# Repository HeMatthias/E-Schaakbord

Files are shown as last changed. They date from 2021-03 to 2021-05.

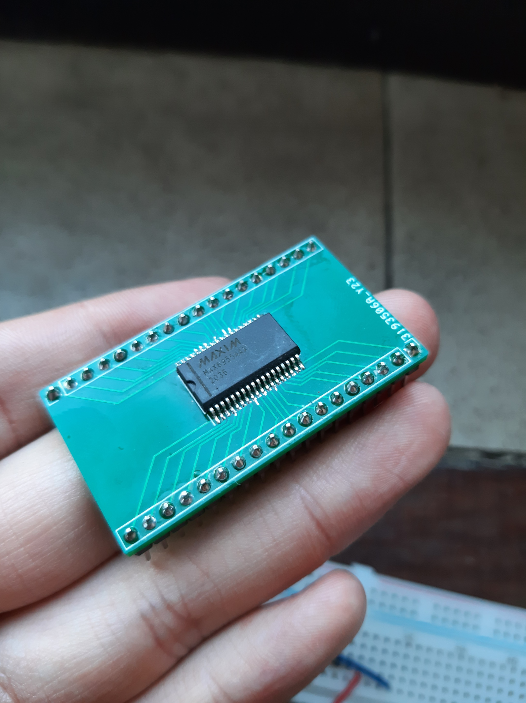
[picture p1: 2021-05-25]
Bundel/Testprint MAX6955.jpg

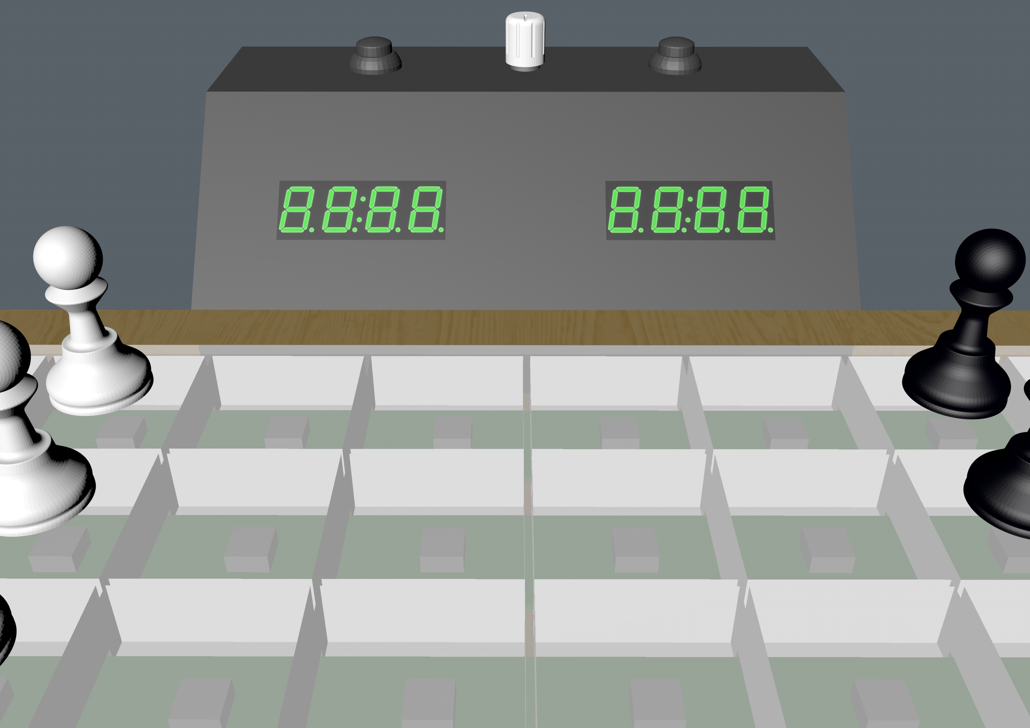
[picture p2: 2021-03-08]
VB Schaakbord2.jpg

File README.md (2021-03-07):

# **♔E-Schaakbord♔**

>#### Gemaakt door: *Hendrickx Matthias*

## Beschrijving

Het E-schaakbord is een elektronisch schaakbord dat a.d.h.v. verschillende elektronica componenten zoals RGB LED’s, sensoren, ... je interactief leert schaken.

Doordat de vakken onder de pionnen belicht worden is er de mogelijkheid om aan te tonen welke stap de pion kan zetten die men opheft of om weer te geven welke er kunnen geslagen worden.

Er bevindt zich ook rechts van het E-schaakbord 2 klokken/timers (7-segmenten) die men eventueel kan instellen hoeveel tijd iedere persoon kan spelen.

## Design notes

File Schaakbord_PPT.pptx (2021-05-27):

## Project: E-Schaakbord

Matthias Hendrickx

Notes: Mijn naam is Matthias Hendrickx, ik ben 20 jaar en heb de richting elektriciteit-elektronica gestudeerd.

Vandaag ga ik u wat meer vertellen over mijn project genaamd E-schaakbord.

## Schaakbord

- Inleiding
- Hardware
- Besluit
- Demonstratie

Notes: Eerst ga ik een inleiding geven, vervolgens de hardware uitleggen,
mijn besluiten trekken en ten slotte een demonstratie geven.

## inleiding

Wat?
Hoe?
Problemen?
Oplossingen:

Elektronisch Schaakbord
STM32 (in C)
Complexe driver, afstand bepalen
Testprint, opzoekingswerk + berekening

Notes: Wat is mijn project en hoe heb ik verschillende dingen moeten oplossen?
Mijn project gaat over een elektronisch schaakbord dat verschillende functies heeft, zoals het magnetisch bepalen waar de pionnen staan.
Het volledige schaakbord wordt bestuurd door middel van een STM32 die ik in C taal geprogrammeerd heb.
Hierbij heb ik mijn eigen library’s gemaakt voor de verschillende componenten die ik later uitleg.
Tijdens het kiezen van de juiste componenten begreep ik niet hoe een IC werkte,
daarmee heb ik een testprint gemaakt om deze volledig uit te testen.
Om de afstand van de pionnen te bepalen heb ik moeten opzoeken hoe ver magneet sensoren kunnen schakelen,
en heb ik moeten berekenen de afstand van het belichte oppervlak.

## Hardware – Blokschema

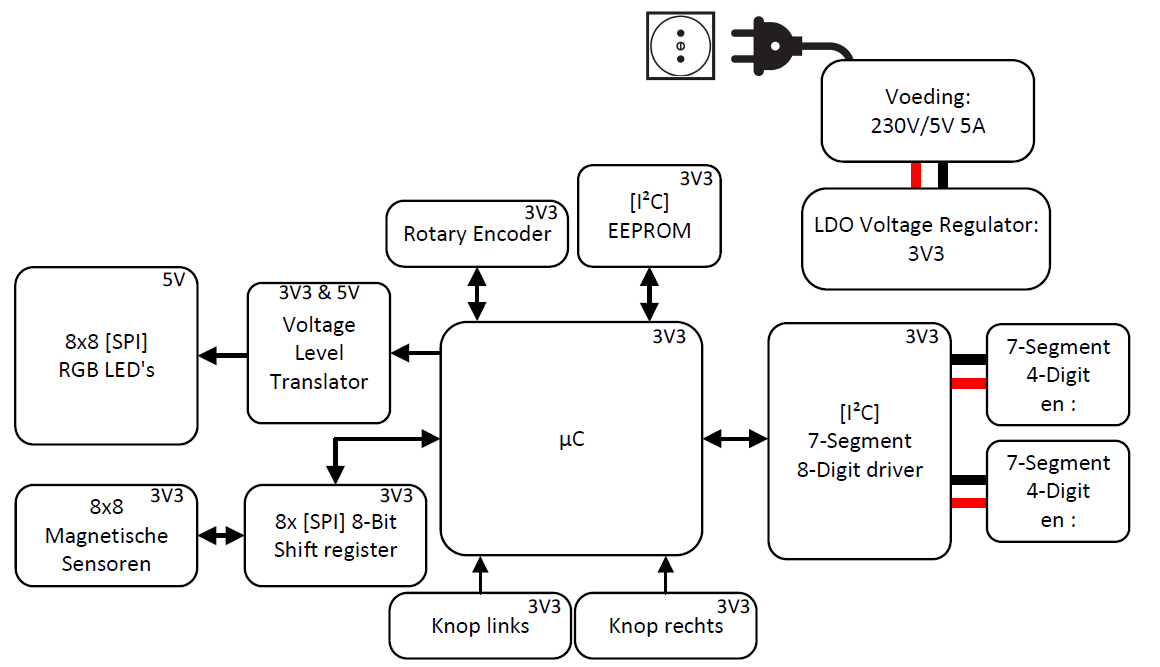
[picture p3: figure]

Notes: Dit is het blokschema van het E-Schaakbord, iedere blok ga ik in de volgende slides bespreken.

## Hardware – Voeding

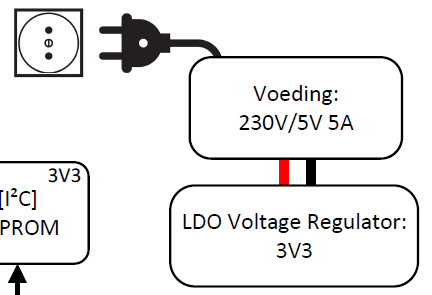
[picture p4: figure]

5V Voeding:
5V x 6A = 30W
LDO Regelaar 3V3: (NCP1117)
5V → 3V3
1500mA Max > ±306mA
IQMAX = 10mA

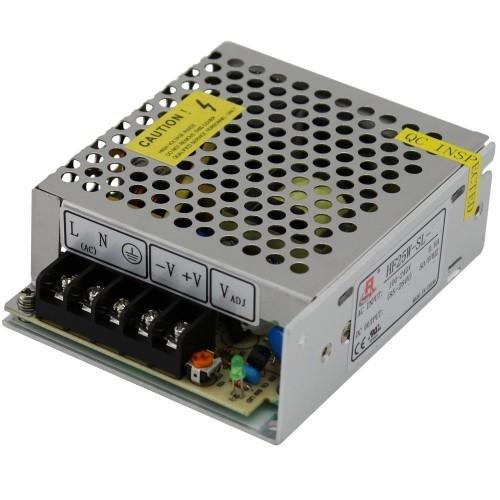
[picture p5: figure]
5V 5A Power Supply at Rs 250/piece | CCTV Power Supply | ID: 17931879912
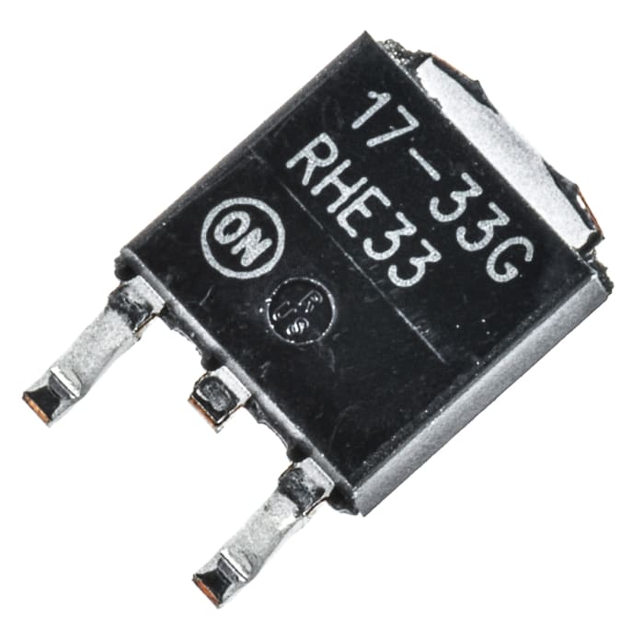
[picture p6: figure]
NCP1117DT33G ON Semiconductor | ON Semiconductor NCP1117DT33G, LDO Regulator, 1A, 3.3 V, ±1% 3-Pin, DPAK | 516-5865 | RS Components

## Hardware – STM32F1xx

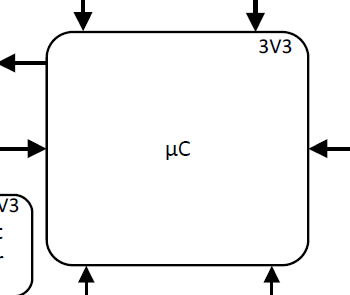
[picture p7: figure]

- µC: (STM32F101RDT6)
  - 32-bit
  - ARM Cortex-M3
  - 36MHz
- Programmeren via ST-Link V2:
  - USB naar SWD(Seriële Wire Debugger)
  - Boot mode in ROM

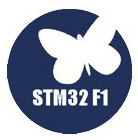
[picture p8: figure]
STM32F1 - Sklep Kamami
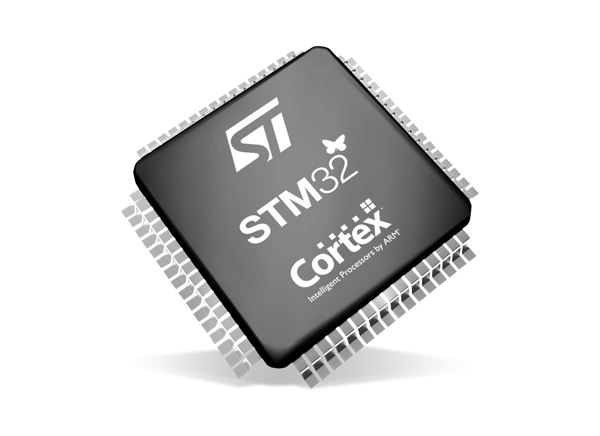
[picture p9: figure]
STM32 Microcontrollers - STMicro | Mouser
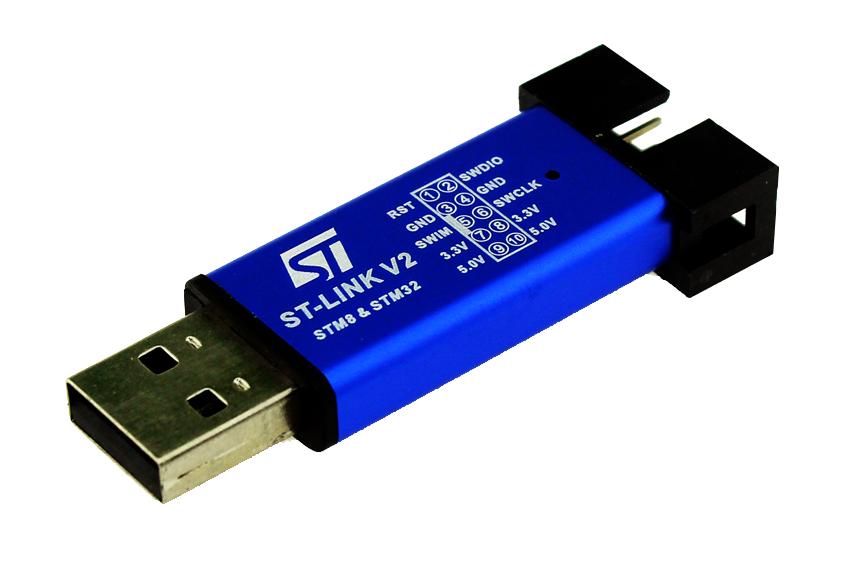
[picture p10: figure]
ST-Link V2 STM8 / STM32 programmer - Opencircuit

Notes: Zoals ik al eerder zei zal ik gebruik maken van de STM32 hieruit heb ik de STM32F101 gekozen, deze had de gewenste protocol poorten,
Deze is een 32-bit µC, en heeft een ARM Cortex-M3 hiermee kan ik zeer eenvoudig in C programmeren.
Verder laat ik de µC ook draaien op 36MHz.
Om de STM32 te programmeren maak ik gebruik van de ST-Link V2, die ik gebruik als Seriele Wire Debugger.
Het programma zal ik ook in het systeem geheugen steken, de ROM.

## Hardware – Geheugen

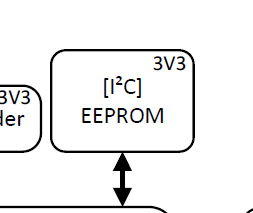
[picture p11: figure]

- EEPROM: (M24C04)
  - Opslaan score vorig spel
  - I²C (SCL, SDA)
  - 4kbit

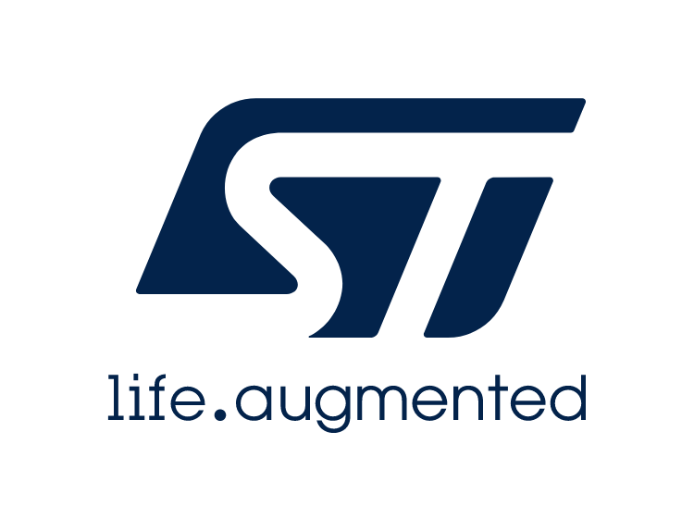
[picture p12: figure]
Home - STMicroelectronics
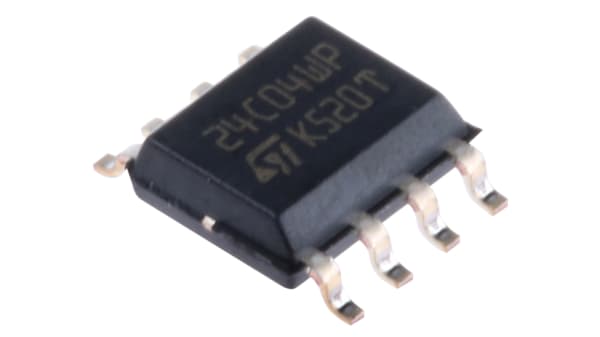
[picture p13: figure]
Mémoire EEPROM en série, M24C04-WMN6P, 4Kbit, 900ns SOIC, 8 broches | RS Components

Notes: Omdat ik niet zeker was of ik veel software moest permanent opslaan maak ik toch gebruik van een EEPROM.
Hiermee zal ik de vorige score van het spel opslaan zodanig dat er met dezelfde score verder gespeeld kan worden.
Deze EEPROM stuur ik aan via I²C en maak ik dus gebruik van een Seriele klok en de Seriele data.
Ik heb gekozen voor een maximale opslag capaciteit van 4kilo bits.

## Hardware – Interface

- Drukknop:
  - Ontdenderen
τ = R x C = 20kΩ x 100nF
τ = 2mS ≈ 3V3 x 66,6% = 2,2V = “1”
- Rotary Encoder:
  - Links & rechts draaien
  - Knop wanneer ingedrukt

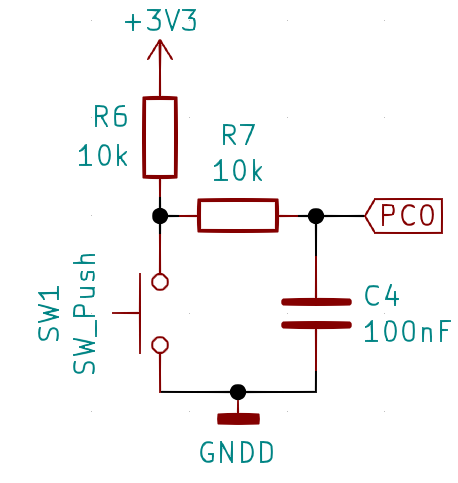
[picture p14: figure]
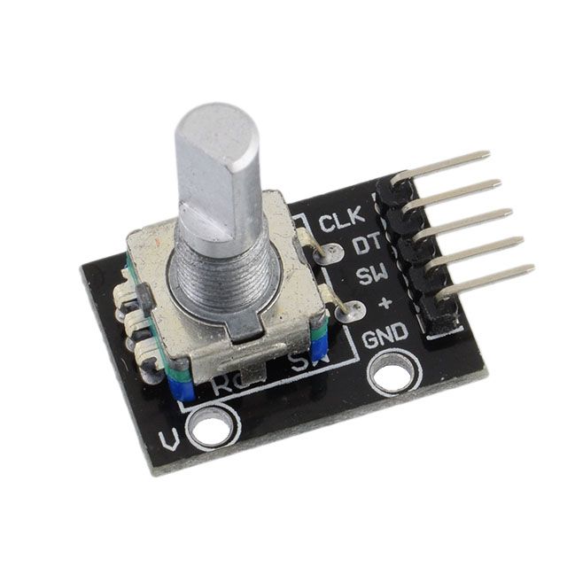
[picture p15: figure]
Rotary encoder moduly | GM electronic COM

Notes: Daarnaast maak ik ook gebruik van 2 drukknoppen, deze worden gebruikt voor de schaakklok te activeren.
Deze zal ik ook hardware matig ontdenderen, deze heb als volgende berekend:
Tau = de weerstand maal de condensator, hiermee kom ik uit op 2mS.
Dan bedraagt de spanning 2,2V en is dus een logische één
Een rotary encoder gebruik ik om op voorhand de schaakklok in te stellen en de kleur van de vakken te kiezen.
Deze kan men naar links en rechts draaien en ook induwen om de selectie te bevestiggen.

## Hardware – SENSOR

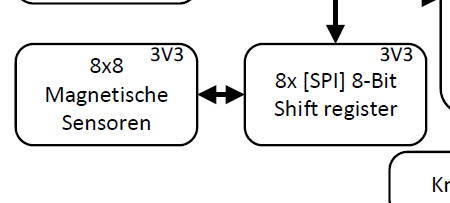
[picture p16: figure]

Magneet sensor: (AH3572)
Omnipolair (N & Z)
20 gauss
Open Drain (Pull-up)
Shift register: (SN74HC165)
PISO (Parallel In Serieel Out)
SPI (SCK → CLK | CS → SH/LD | MISO → Qh)

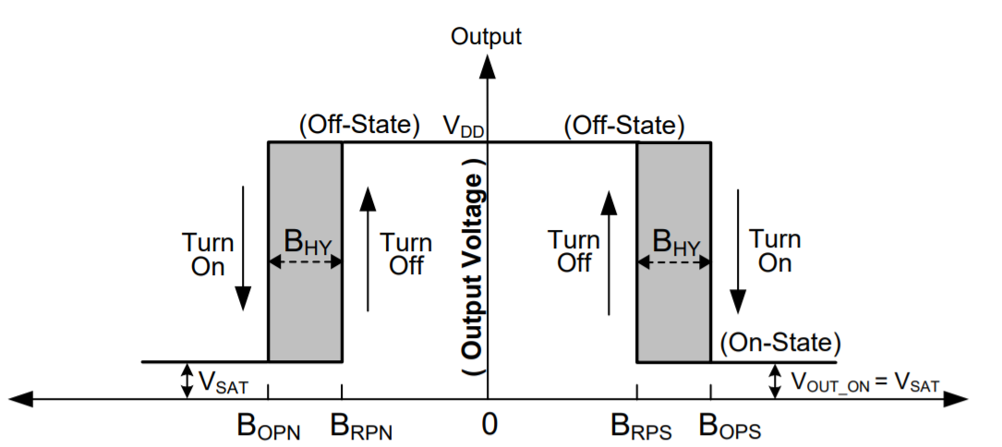
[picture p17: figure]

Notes: Voor het kiezen van een sensor moest ik opzoek gaan naar een magneet sensor.
Hiervoor koos ik een omnipolaire magneet sensor te gebruiken,
deze zullen schakelen als de Noord of de Zuid in sterker is dan 20 gauss of te wel 2milli Tesla.
De uitgang van de AH3572 is een open drain en zal ik via een externe pull-up weerstand schakelen.
Omdat ik 64 magneet sensoren heb zal ik gebruik maken van een shift register.
Hierbij koos ik voor een PISO (parallel in Serieel Uit)
Deze kan ik ook aansturen via het SPI protocol.

## Hardware – RGB LED’s

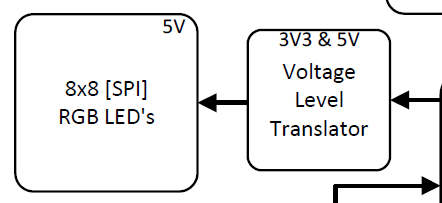
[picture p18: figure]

Adresseerbare RGB LED’s: (APA102C)
5V!
SPI (CLK, DI, ~~CS~~)
Globale intensiteit
RGB kleur intensiteit
Voltage Translator: (SN74LVC2T45)
5V → 3V3

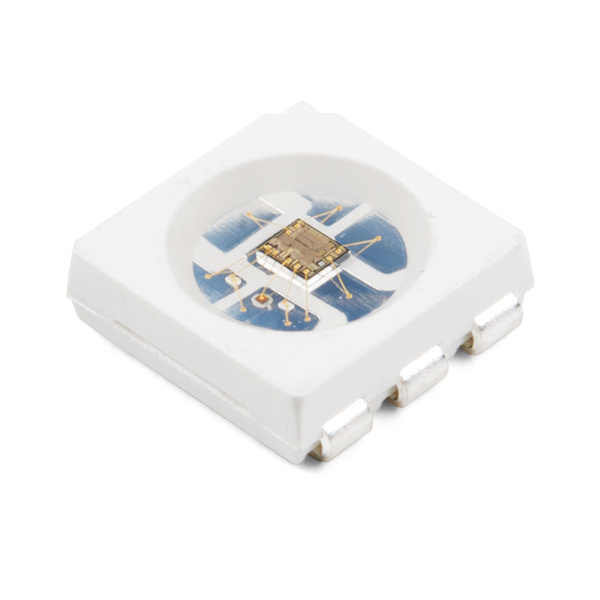
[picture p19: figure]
APA102 Addressable LED Hookup Guide - learn.sparkfun.com

## Hardware – Klok

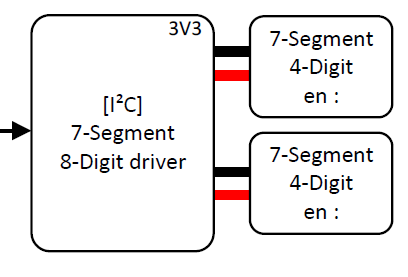
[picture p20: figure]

7 Segment 4 Digit :
Groen
20mA/segment
3200µcd
7 Segment Driver: (MAX6955)
I²C (SCL, SDA)
Tot 16 digit 7 segment aansturen
Individuele intensiteit controle

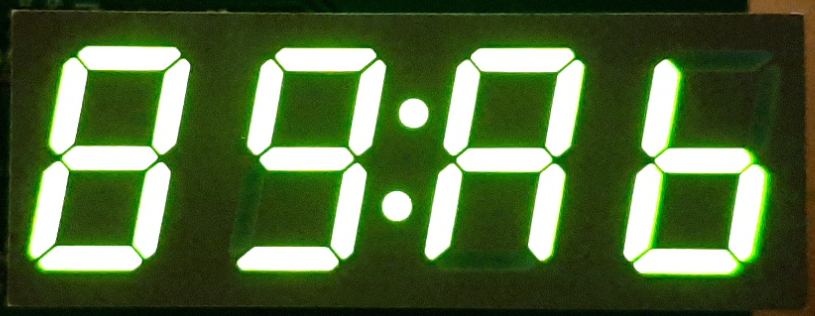
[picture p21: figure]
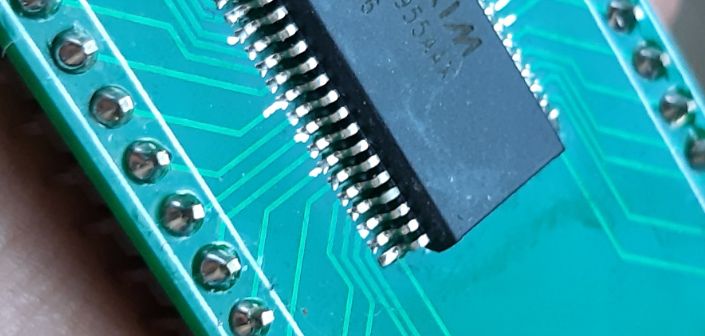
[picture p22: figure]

## besluit

De behuizing | Hardware geen fout
PCB paar fouten Pin ontbreekt | Software verliep vlot
Vertraging PCB | Solderen van SMD
| Afstand klopt

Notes: Ten slotte de besluiten die ik doorheen het project ontdekt heb.

## Demonstratie

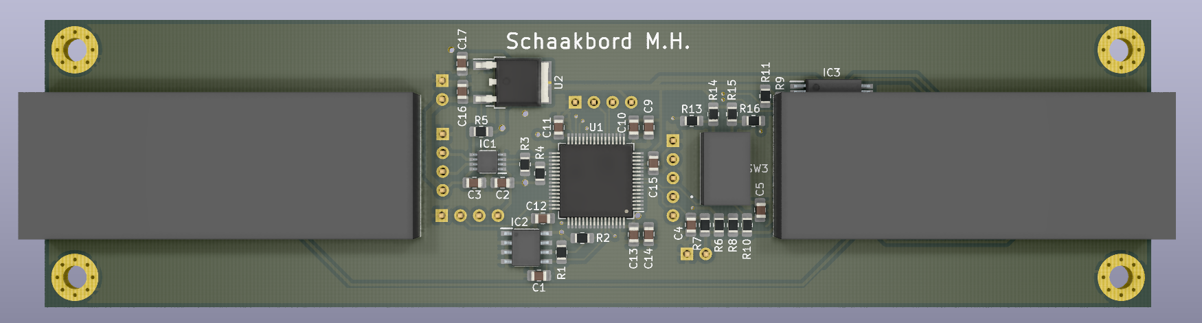
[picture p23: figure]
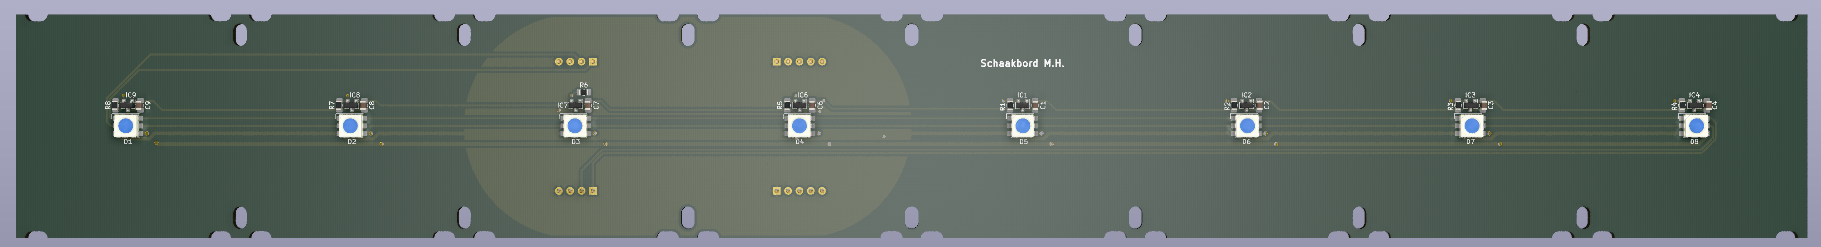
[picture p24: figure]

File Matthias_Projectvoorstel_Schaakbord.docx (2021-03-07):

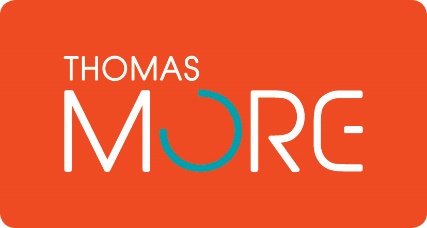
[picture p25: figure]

| Naam Matthias Hendrickx r-nummer r0782520 1 Vak Practice Enterprise 2 1 Datum 29/11/2020 1 Klas Embedded-Hardware 2EH1 1

Projectvoorstel: E-Schaakbord

Korte beschrijving

Voor het vak Practice Enterprise 2 zal ik een educatief E-schaakbord maken waar de E staat voor Elektronisch. Dit doe ik a.d.h.v. verschillende RGB LED’s, 7-Segmenten, sensoren en meer. De bedoeling is dat je met dit bord leert schaken. Aan het begin van het spel kan men de speeltijd instellen a.d.h.v. een rotary encoder en doordat de vakken onder de pionnen belicht worden is er de mogelijkheid om aan te tonen welke stappen iedere pion kan zetten.

Blokdiagram

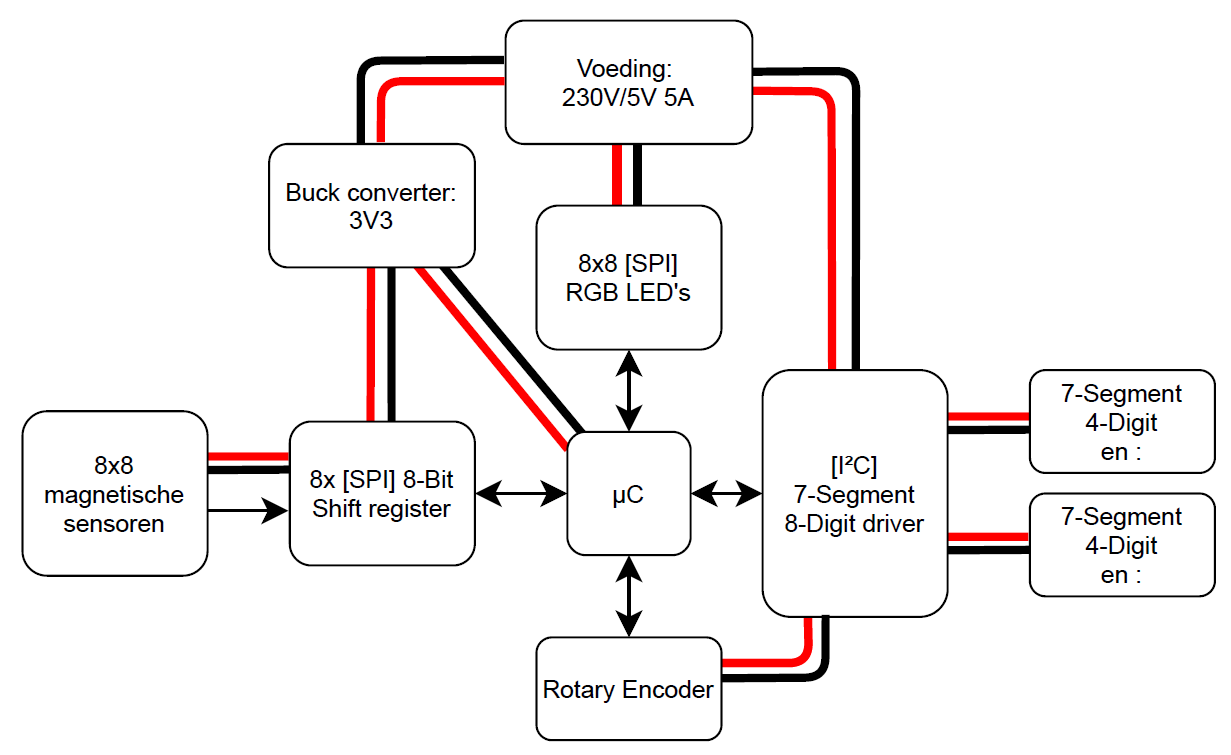
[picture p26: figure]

- Voeding: Mean Well, RS-25-5
- Buck converter: Texas Instruments, TPS62203
- µC: STMicroelectronics, STM32F101RB
- RGB LED’s: Sparkfun, RGB APA102C 5050
- Rotary encoder: Bourns, PEC11R-4225F-S0012
- Shift register: Texas Instruments, SN74HC165
- Magnetische sensor: Toshiba, TCS40DPR
- 7-Segment 8-Digit driver: Maxim Integrated, MAX6955
- 7-Segment 4-Digit display: Vishay, TDCG1050M

Componenten/tool keuze

STM32F101 - Arm Cortex-M3 Microcontrollers (MCU) 36 MHz - STMicroelectronics

Als microcontroller (µC) heb ik gekozen voor de STM32F1 series omdat deze een goed prijs/kwaliteit bood, in deze series heeft men de keuze tussen 16kB tot 1MB Flash geheugen waarvan ik 128kB koos. Daarnaast gebruik ik de 64-pin LQFP-package voor als ik eventueel niet toekom aan geheugen kan ik verhogen zonder de PCB aan te passen.

STMicroelectronics Updates STM32CubeMX MCU Configurator with Multi-Panel GUI for Improved Developer Experience

De STM32F1 series maakt ook gebruik van de wel bekende STM32CubeIDE waarin ik men µC kan instellen en programmeren.

Om mijn programma te uploaden en te debuggen zal ik gebruik maken van

een ST-Link V2.

Ximimark ST-Link V2 Shell Programming Un- Buy Online in Trinidad and Tobago at Desertcart

Hierdoor kan ik vlot communiceren van de computer naar de µC en visa versa.

Marktonderzoek(wat bestaat er al?)

Over het algemeen bestaan er 2 soorten elektronische schaakborden.

- Waarmee men tegen een computer speelt. Deze werken meestal op batterij omdat de meeste via een scherm de posities weergeven.


- Of voor schaakwedstrijden met een aparte digitale klok. Hier wordt het schaakbord via een aparte kabel of bluetooth verbonden met de klok. Deze worden meestal gevoed door hem in het stopcontact te steken.

Schachcomputer DGT 3000 Pi Schachcomputer

Technologie verkenning(principes, evaluatieborden, papers, ...)

Voor technologie verkenning ben ik opzoek gegaan naar een geschikte microcontroller(µC). Hiervoor heb ik van alle parameters opgezocht van welke soorten allemaal bestaan bv: 8-bit, 32-bit, PIC, ARM, AVR en nog veel meer. Ten slotte heb ik gekozen voor ARM-cortex met 32-bit zodanig dat mijn code niet te complex wordt en geen pagina’s lang is.

Daarna ben ik opzoek gegaan naar µC fabrikanten hiervoor heb ik verschillende websites bestudeert zoals: Microchip, Infineon, Texas Instruments, ...

Ten slotte vond ik STMicroelectronics de meest interessantste omdat ik meer bekend ben met deze fabrikant en een goed platform heeft om te programmeren en dergerlijk. Bij Componenten/tool keuze ga ik wat meer in detail welke STMicroelectronics ik gekozen heb.

Budget raming


Als budget raming heb ik iedere blok van het blokdiagram op de webshop van Mouser opgezocht en kwam ik ±60€ uit +30€ voor de behuizing en dergerlijk.

Pagina 2 van 2

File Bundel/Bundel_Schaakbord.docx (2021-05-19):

# Inhoudstafel

# Voorwoord

TEKST TEKST TEKST ...

# Inleiding

Deze bundel gaat over het project dat ik gemaakt heb voor het vak Practice Enterprise 2, hierbij waren de minimale vereisten dat ik een PCB ontwerp, Software schrijf (liefst in C op een µController) en ten slotte het project een nuttige toepassing heeft. Het is ook belangrijk dat er een veilig project gekozen werd en de kostprijs niet te hoog lag.

Na enkele projectjes dat ik heb voorgesteld koos ik om een elektronisch educatief schaakbord te maken. Hiermee zouw u dan de mogelijkheid krijgen om te leren hoe men iedere pion zet en de werking van een schaakklok. Daarnaast bevat het schaakbord over een puntensysteem dat bijgehouden wordt.

# 1 Hardware

## 1.1 Blokschema


In het blokschema zien we hoe de verschillende blokken verbonden zijn met elkaar maar dit in een vereenvoudigde weergave. Hierbij kan je zien hoe alles logisch met elkaar verbonden is d.m.v. voedingsaansluitingen en communicatielijnen.

Figuur 1, Blokschema

## 1.2 Schema’s


Dit is het aansluiting schema van het hoofdbord, hierin zit: de µC, 7 Segmenten, Rotary Encoder ... Later wordt ieder deel nog besproken.

Figuur 2, Schema hoofdbord


Dit is het aansluiting schema van de borden die zich onderaan de pionnen liggen, Later wordt ieder deel besproken.

Figuur 3, Schema pionnen

## 1.3 Beschrijving

Hierin ga ik ieder deel bespreken en uitleggen hoe ik eventueel iets berekend heb.

### 1.3.1 Schakelende voeding


Het E-Schaakbord wordt gevoed door de 230V AC netspanning die wordt omgezet naar 5V DC d.m.v. een schakelende voeding. De voeding die ik gekozen/berekend heb kan maximaal 5A leveren of in andere woorden 5V*5A=25W .

Dit heb ik berekend a.d.h.v. het maximaal vermogen dat gebruikt kan worden op te tellen van ieder component. Daarmee heb ik gebruik gemaakt van de maximale spanning en stromen die uit de datasheet komen van ieder component.


Tabel 1, Vermogen berekening

Figuur 4, Voorbeeld voeding

Zoals u merkt heb is mijn voeding’s keuze redelijk krap genomen, dit is doordat ik het maximale berekend heb en daarmee juist gekozen heb voor 5A. Het verbruik wordt beperkt d.m.v. de software die ik er insteek, omdat ik nooit al mijn RGB LED’s tegelijk de kleur wit ga maken zal de stroom dus beperkt blijven.

APA102C (RGB Addressable LED’s): kleur Wit Itot=Uin*Iin*Aantal=5V*24,5mA*3*64=4,704A Ptot=Uin*Itot=5V*4,704A=23,52W

APA102C (RGB Addressable LED’s): kleur Blauw Itot=Uin*Iin*Aantal=5V*24,5mA*64=1,568A Ptot=Uin*Itot=5V*1,568A=7,84W

MAX6955 (7 Segment Driver): Ptot=(Uin*35mA)+(Uin -Uled)(DUTY*Iseg*Ndigit) Ptot=(3,3V*35mA)+(3,3V -2V)(15/16*25mA*8)=243,866mW Itot=(Ptot)/(Uin)=(243,866mW)/(3,3V)=73,899mA

STM32F101RDTx (µC):


Itot is gesimuleerd a.d.h.v. CubeMX zijn PCC Tool.

Hierbij heb ik alles ingesteld op het maximum dat ik kan gebruiken i.v.m. het schaakbord: HSI PLL, de CPU Frequency, I/O en meer.

Itot≈20mA

Ptot=Uin*Itot=3,3V*20mA=66mW

Figuur 5, Simulatie stroomverbruik

AH3572 (Magnetic Sensor): Itot=Uin*Iin*Aantal=3,3V*3mA*64=192mA Ptot=Uin*Itot=3,3V*192mA=633,6mW

NCP1117 (LDO Voltage Regulator): Itot=(Uin-Uuit)*Iq=(5,2V-3,2V)*10mA=20mA Ptot=(Uin-Uuit)*Itot=(5,2V-3,2V)*20mA=40mW

### 1.3.3 LDO Voltage Regulator

Nadat de 230V AC omgezet is naar 5V DC zal ik deze 5V omzetten naar 3V3, hiermee zal ik de andere componenten voeden buiten de RGB LED’s.

Ik heb gekozen voor een LDO omdat:

- Het maximaal vermogen onder de 1W was en dus dit vermogen nog gedissipeerd kan worden d.m.v. een LDO.
- Het voordeel is ook dat LDO’s qua structuur simplistisch zijn en dus onafhankelijk zijn van een externe spoel i.t.t. een Buck-Converter.

A.d.h.v. de vorige berekeningen (Tabel 1) kwam ik uit dat de LDO een minimaal vermogen van ±983mW gedissipeerd wordt. Hiermee ben ik dan aan de slag gegaan en opzoek gegaan naar een LDO en kwam ik uit op de NCP1117.

Deze heb ik gekozen door de volgende berekeningen te maken: P_(DMAX) =(T_J – T_A)/(Θ_(JA))=(150°C-40°C)/(67°C/W)=1642mW

P_(MAX) <P_(DMAX) →983mW<1642mW

Deze berekeningen heb ik geraadpleegd via een handig document van Microchip<link>

### 1.3.4 µC

Dit is een zeer belangrijk keuze die gemaakt moet worden, daarmee heb ik genoeg research gedaan op het internet d.m.v. online guides op te zoeken en meer.

De eerste vraag die ik mezelf stelde is of ik een 8-bit of 32-bit microcontroller kies. Ik koos voor een 32-bit microcontroller wegens volgende redenen:

- Communicatieprotocollen zoals SPI & I²C zijn eenvoudiger te implementeren.
- Om lengte/grootte van software te beperken.
- Eenvoudiger te debuggen.

Nu was de keuze voor welke fabrikant ik zal gaan, hier waren vooral 2 uitblinkers bij de STM32 of PIC32. Ik koos voor de STM32 wegens volgende redenen:

- Meer gekend in hoe deze ge programmeert wordt en debugt.
- Zeer stabiel en handige Toolchain/IDE ondersteuning.

Ten slotte ben ik opzoek gegaan naar een STM32 die een genoeg aantal I²C en SPI-protocollen had en die genoeg geheugen heeft.


Toen kwam ik uit op de STM32F101RDT6, deze bevindt zich in een LQFP-64 package dat nog handsoldeerbaar is en ook de mogelijkheid heeft in dezelfde package een groter geheugen te kiezen of een andere reeks.

Figuur 6, Circuit Diagram

### 1.3.5 RGB LED’s

Om de schaakvakken een kleur te geven maak ik gebruik van adresseerbare RGB LED’s, hierdoor kan ik elk vak individueel een andere kleur geven wat dat belangrijk is voor aan te duiden wat de pion hun mogelijke zetten zijn en meer.

Ik heb gekozen om gebruik te maken van de APA102C LED’s omdat:

- Worden aangestuurd via het standaard SPI-Protocol.
- Heeft een snellere CLK-frequentie maximaal 1,2MHz.


- Beschikt over een aparte PWM-instelling om de lichtsterkte te regelen.

Figuur 7, Illustratie APA102C

Understanding the APA102 “Superled” – Tim's Blog

Zoals u hierboven ziet wordt de APA102C’s aangestuurd:

Figuur 8, APA102C SPI-Protocol

Eerst wordt er een Start Frame gestuurd met 4 bytes die ‘0’ zijn.

Daarna wordt er de data van de eerste LED gestuurd met als inhoud:

1. “111” om te beginnen, 3 bits.
2. Daarna de data wat de licht intensiteit is van al de LED’s, 5bits.
3. De lichtintensiteit van de kleur blauw, 1 byte.
4. De lichtintensiteit van de kleur groen, 1 byte.
5. De lichtintensiteit van de kleur rood, 1 byte.

Vervolgens stuurt men de data door van de tweede LED.

Ten slotte kan men een eind frame sturen die bestaat uit allemaal enen, de grote van deze frame is gelijk aan het totaal aantal LED’s delen door 2.

Dus het schaakbord bestaat uit 64 RGB LED’s, dat wil zeggen dat er 32 keer 4 bytes die ‘1’ zijn (eind frame) verstuurt moet worden. Het is gemakkelijker om op het einde een Start frame sturen om terug opnieuw te beginnen waardoor ik zo min mogelijk tijdverlies.

### 1.3.6 Voltage Level Translator


Om de APA102C’s te laten communiceren met de µC zal ik de 3V3 logica moeten omzetten naar 5V logica. Om deze om te zetten maak ik gebruik van een Voltage Level Translator. Ik heb gekozen voor de SN74LVC2T45, hiermee zal ik de SCK (seriële clock) en de SDI (seriële data in) omzetten naar 5V logica.

Figuur 9, Schema Voltage Translator

### 1.3.7 Rotary Encoder

Voor het schaakbord gebruiksvriendelijker te maken bevindt er zich een rotary encoder tussen de 2 drukknoppen op de schaakklok. Hiermee kan voor het spel begint de tijden ingesteld worden en de kleur van de schaakvakken.

In-Depth: How Rotary Encoder Works and Interface It with Arduino

Een rotary encoder werkt als volgend:

Figuur 10, Werking Rotary Encoder

Wanneer er één stand in wijzerzin (↻) gedraaid wordt zal Terminal A 90° voor-ijlen omdat deze voor Terminal B contact zal maken met de GND of de 3V3. Als daar na gelijk er één stand in wijzerzin (↻) opnieuw gedraaid wordt zal nu Terminal B op hetzelfde contact van Terminal A staan.

Dit is omgekeerd als men één stand in tegenwijzerzin (↺) draait zal Terminal B 90° voor-ijlen omdat deze voor Terminal A contact zal maken met de GND of de 3V3. hetzelfde als er daar na gelijk één stand in tegenwijzerzin (↺) opnieuw gedraaid wordt zal nu Terminal A op hetzelfde contact staan als dat van Terminal B.


Deze terminals worden vervolgens zo aangesloten op de STM32:

Figuur 11, Schema Rotary Encoder

In de software zal nu gewoon iedere pin continu uitgelezen worden en als er een verandering plaats vindt zal men te weten komen welke richting er gedraaid werd.

De rotary encoder bevat ook een schakelaar die schakelt wanneer op de knop geduwd wordt, hiermee is alles wat meer gebruiksvriendelijk zoals om een actie te voltooien.

### 1.3.8 EEPROM

EEPROM of Electrically Erasable Programmable Read-Only Memory is een geheugen IC die data opgeslagen houdt terwijl de IC niet gevoed wordt, dit heet men ook permanent geheugen. EEPROM’s kunnen ook hun blokken data (1 byte) individueel her programmeren waardoor er niet alles verwijderd moet worden. Het nadeel is wel dat deze niet oneindig keer herschreven kan worden, maar tegenwoordig kunnen de meeste meer dan 1 miljoen keer herschreven worden.

Ik heb gekozen voor de M24C04 omdat deze via I²C te werk gaat en een geheugen heeft van 4kbits of 512bytes. Hierin zal ik de score zetten van het vorig spel.

# besluit….

Typ hier je besluit

Pagina 2 van 2

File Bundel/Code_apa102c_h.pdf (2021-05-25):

APA102C.h

2 * APA102C.h
7
8 #ifndef INC_APA102C_H_
9 #define INC_APA102C_H_
10
11 void LED_Rood(uint8_t brightness);
12 void LED_Groen(uint8_t brightness);
13 void LED_Blauw(uint8_t brightness);
14 void LED_RGB(uint8_t brightnessR, uint8_t brightnessG, uint8_t brightnessB); 15 void LED_Start(void);
16
17 #endif /* INC_APA102C_H_ */
18

Page 1

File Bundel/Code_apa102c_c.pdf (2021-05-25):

APA102C.c; 2 * APA102C.c 7 #include "main.h" 8 9 uint32_t t = 1; 10 int8_t i = 0; 11 12 void LED_Rood(uint8_t brightness){ 13 for (i = 0; i < 8; i++) { 14 HAL_GPIO_WritePin(SPI2_MOSI_GPIO_Port,SPI2_MOSI_Pin,GPIO_PIN_SET); 15 SysTickDelayCount2(t); 16 HAL_GPIO_WritePin(SPI2_SCK_GPIO_Port,SPI2_SCK_Pin,GPIO_PIN_SET); 17 SysTickDelayCount2(t); 18 HAL_GPIO_WritePin(SPI2_SCK_GPIO_Port,SPI2_SCK_Pin,GPIO_PIN_RESET); 19 } 20 for (i = 0; i < 16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

APA102C.c

63 SysTickDelayCount2(t);
64 HAL_GPIO_WritePin(SPI2_SCK_GPIO_Port,SPI2_SCK_Pin,GPIO_PIN_SET); 65 SysTickDelayCount2(t);
66 HAL_GPIO_WritePin(SPI2_SCK_GPIO_Port,SPI2_SCK_Pin,GPIO_PIN_RESET); 67 }

### 68 for (i = 0; i < 8; i++) {

69 HAL_GPIO_WritePin(SPI2_MOSI_GPIO_Port,SPI2_MOSI_Pin,GPIO_PIN_RESET); 70 SysTickDelayCount2(t);
71 HAL_GPIO_WritePin(SPI2_SCK_GPIO_Port,SPI2_SCK_Pin,GPIO_PIN_SET); 72 SysTickDelayCount2(t);
73 HAL_GPIO_WritePin(SPI2_SCK_GPIO_Port,SPI2_SCK_Pin,GPIO_PIN_RESET); 74 }
75 }
76

### 77 void LED_Blauw(uint8_t brightness){ 78 for (i = 0; i < 8; i++) {

79 HAL_GPIO_WritePin(SPI2_MOSI_GPIO_Port,SPI2_MOSI_Pin,GPIO_PIN_SET); 80 SysTickDelayCount2(t);
81 HAL_GPIO_WritePin(SPI2_SCK_GPIO_Port,SPI2_SCK_Pin,GPIO_PIN_SET); 82 SysTickDelayCount2(t);
83 HAL_GPIO_WritePin(SPI2_SCK_GPIO_Port,SPI2_SCK_Pin,GPIO_PIN_RESET); 84 }

### 85 for (i = 7; i >= 0; i--) {

86 uint8_t k = brightness >> i;

### 87 if (k & 1){

88 HAL_GPIO_WritePin(SPI2_MOSI_GPIO_Port,SPI2_MOSI_Pin,GPIO_PIN_SET); 89 }else{
90 HAL_GPIO_WritePin(SPI2_MOSI_GPIO_Port,SPI2_MOSI_Pin,GPIO_PIN_RESET); 91 }
92 SysTickDelayCount2(t);
93 HAL_GPIO_WritePin(SPI2_SCK_GPIO_Port,SPI2_SCK_Pin,GPIO_PIN_SET);
94 SysTickDelayCount2(t);
95 HAL_GPIO_WritePin(SPI2_SCK_GPIO_Port,SPI2_SCK_Pin,GPIO_PIN_RESET); 96 }

### 97 for (i = 0; i < 16; i++) {

98 HAL_GPIO_WritePin(SPI2_MOSI_GPIO_Port,SPI2_MOSI_Pin,GPIO_PIN_RESET); 99 SysTickDelayCount2(t);
100 HAL_GPIO_WritePin(SPI2_SCK_GPIO_Port,SPI2_SCK_Pin,GPIO_PIN_SET); 101 SysTickDelayCount2(t);
102 HAL_GPIO_WritePin(SPI2_SCK_GPIO_Port,SPI2_SCK_Pin,GPIO_PIN_RESET); 103 }
104 }
105
106 void LED_RGB(uint8_t brightnessR, uint8_t brightnessG, uint8_t brightnessB){ 107 for (i = 0; i < 8; i++) {
108 HAL_GPIO_WritePin(SPI2_MOSI_GPIO_Port,SPI2_MOSI_Pin,GPIO_PIN_SET); 109 SysTickDelayCount2(t);
110 HAL_GPIO_WritePin(SPI2_SCK_GPIO_Port,SPI2_SCK_Pin,GPIO_PIN_SET); 111 SysTickDelayCount2(t);
112 HAL_GPIO_WritePin(SPI2_SCK_GPIO_Port,SPI2_SCK_Pin,GPIO_PIN_RESET); 113 }
114 for (i = 7; i >= 0; i--) {
115 uint8_t k = brightnessB >> i;
116 if (k & 1){
117 HAL_GPIO_WritePin(SPI2_MOSI_GPIO_Port,SPI2_MOSI_Pin,GPIO_PIN_SET); 118 }else{
119 HAL_GPIO_WritePin(SPI2_MOSI_GPIO_Port,SPI2_MOSI_Pin,GPIO_PIN_RESET);

Page 2

APA102C.c

120 }
121 SysTickDelayCount2(t);
122 HAL_GPIO_WritePin(SPI2_SCK_GPIO_Port,SPI2_SCK_Pin,GPIO_PIN_SET); 123 SysTickDelayCount2(t);
124 HAL_GPIO_WritePin(SPI2_SCK_GPIO_Port,SPI2_SCK_Pin,GPIO_PIN_RESET); 125 }
126 for (i = 7; i >= 0; i--) {
127 uint8_t k = brightnessG >> i;
128 if (k & 1){
129 HAL_GPIO_WritePin(SPI2_MOSI_GPIO_Port,SPI2_MOSI_Pin,GPIO_PIN_SET); 130 }else{
131 HAL_GPIO_WritePin(SPI2_MOSI_GPIO_Port,SPI2_MOSI_Pin,GPIO_PIN_RESET); 132 }
133 SysTickDelayCount2(t);
134 HAL_GPIO_WritePin(SPI2_SCK_GPIO_Port,SPI2_SCK_Pin,GPIO_PIN_SET);
135 SysTickDelayCount2(t);
136 HAL_GPIO_WritePin(SPI2_SCK_GPIO_Port,SPI2_SCK_Pin,GPIO_PIN_RESET); 137 }
138 for (i = 7; i >= 0; i--) {
139 uint8_t k = brightnessR >> i;
140 if (k & 1){
141 HAL_GPIO_WritePin(SPI2_MOSI_GPIO_Port,SPI2_MOSI_Pin,GPIO_PIN_SET); 142 }else{
143 HAL_GPIO_WritePin(SPI2_MOSI_GPIO_Port,SPI2_MOSI_Pin,GPIO_PIN_RESET); 144 }
145 SysTickDelayCount2(t);
146 HAL_GPIO_WritePin(SPI2_SCK_GPIO_Port,SPI2_SCK_Pin,GPIO_PIN_SET);
147 SysTickDelayCount2(t);
148 HAL_GPIO_WritePin(SPI2_SCK_GPIO_Port,SPI2_SCK_Pin,GPIO_PIN_RESET); 149 }
150 }
151
152 void LED_Start(){
153 for (i = 0; i < 32; i++) {
154 HAL_GPIO_WritePin(SPI2_MOSI_GPIO_Port,SPI2_MOSI_Pin,GPIO_PIN_RESET); 155 SysTickDelayCount2(t);
156 HAL_GPIO_WritePin(SPI2_SCK_GPIO_Port,SPI2_SCK_Pin,GPIO_PIN_SET); 157 SysTickDelayCount2(t);
158 HAL_GPIO_WritePin(SPI2_SCK_GPIO_Port,SPI2_SCK_Pin,GPIO_PIN_RESET); 159 }
160 }
161

Page 3

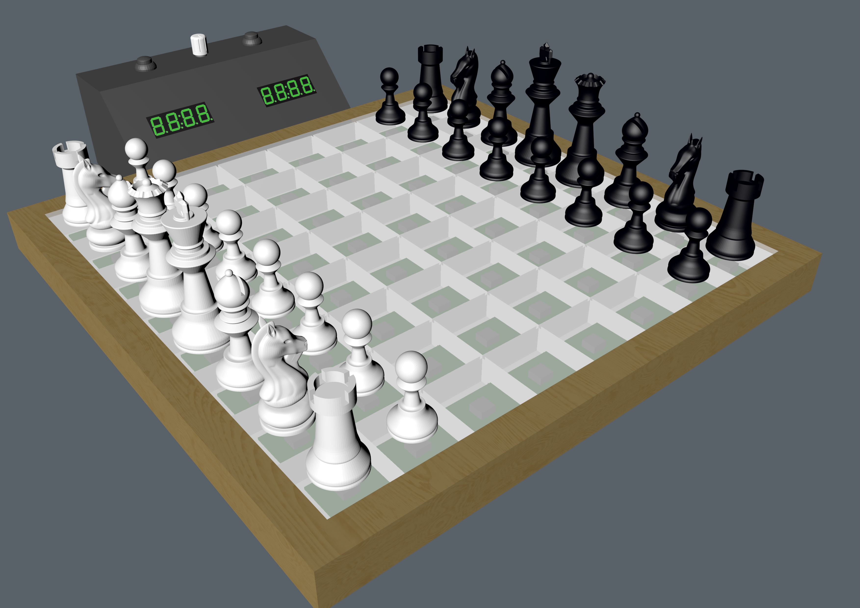
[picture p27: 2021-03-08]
VB Schaakbord1.jpg

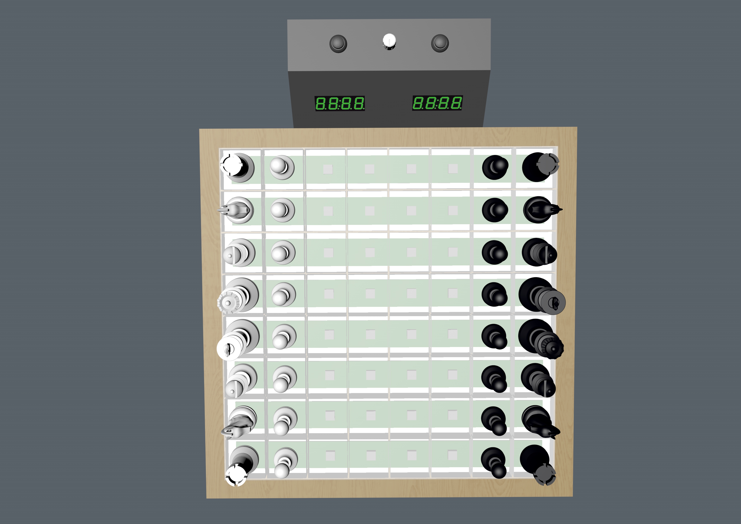
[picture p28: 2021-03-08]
VB Schaakbord3.jpg

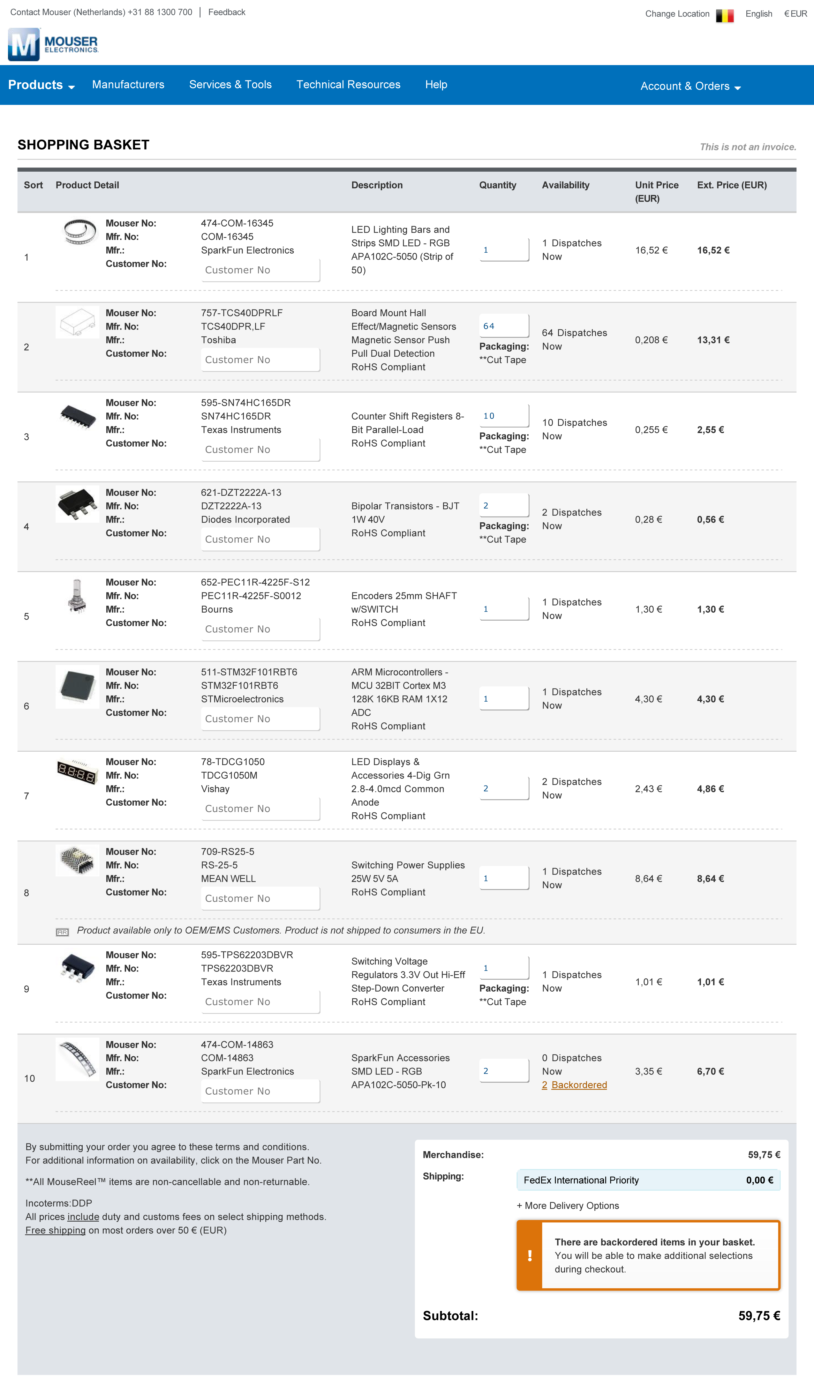
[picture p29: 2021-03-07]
Budget.png

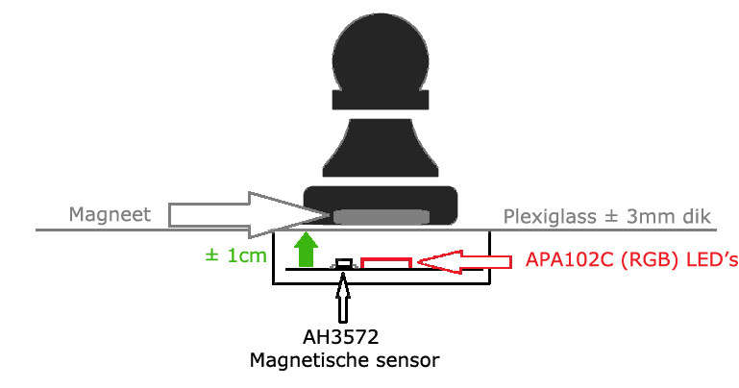
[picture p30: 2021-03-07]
voorbeeld sensor.jpg

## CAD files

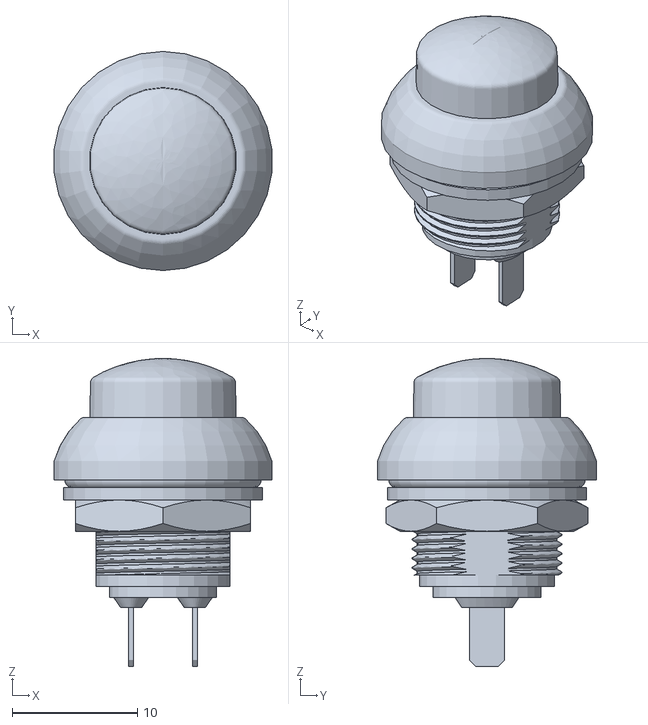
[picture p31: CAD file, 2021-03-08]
3D Simulatie/Drukknop.stl
17.4 x 17.5 x 24.6

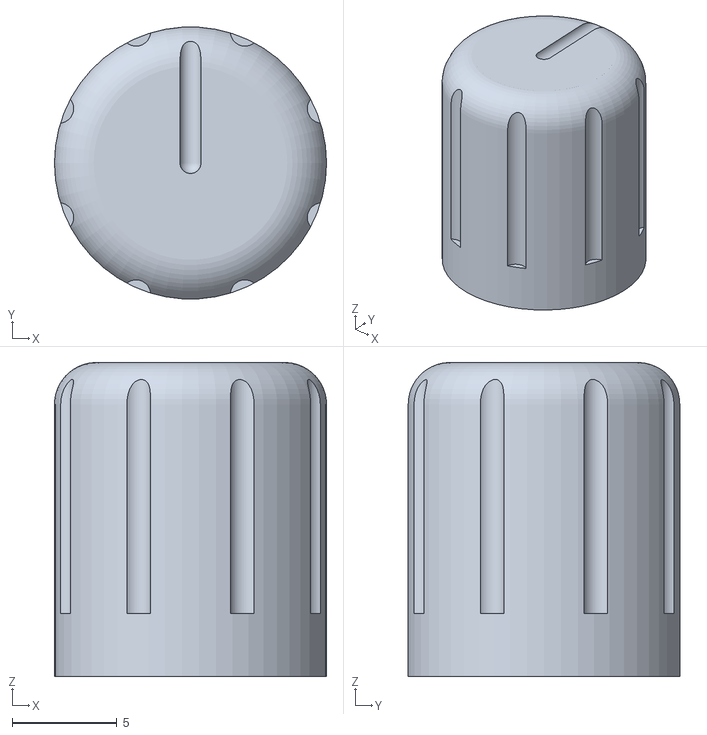
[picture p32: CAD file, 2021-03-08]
3D Simulatie/Knop rotary encoder.stl
13.0 x 13.0 x 15.0

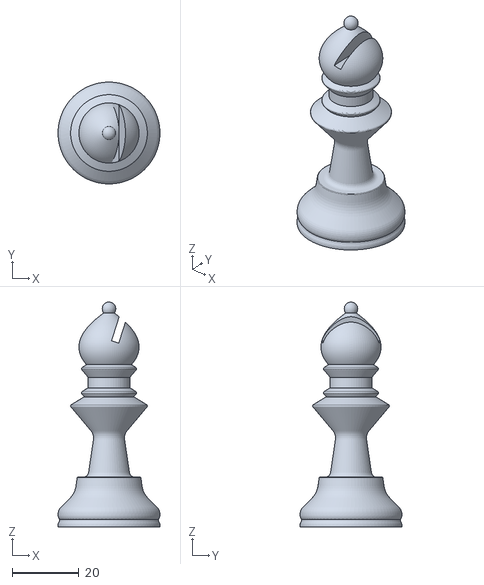
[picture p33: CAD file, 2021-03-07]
3D Simulatie/Bishop.stl
30.5 x 30.5 x 67.3

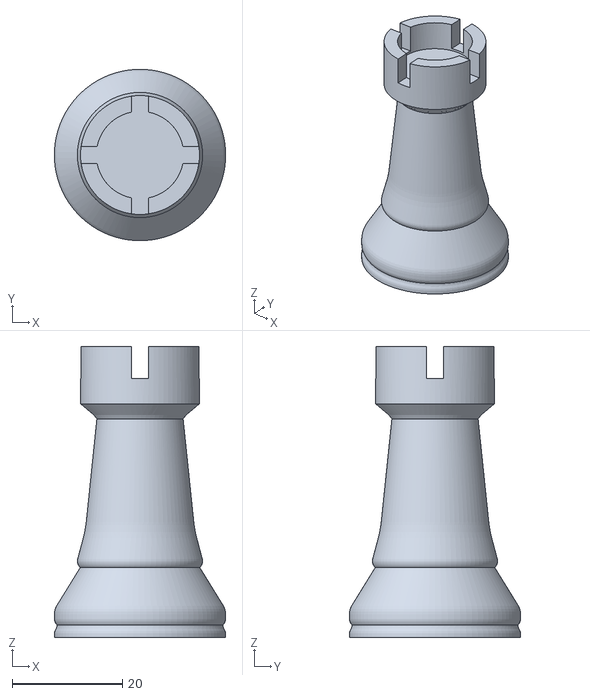
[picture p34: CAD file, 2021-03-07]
3D Simulatie/Rook-NEW.stl
31.1 x 31.1 x 52.8

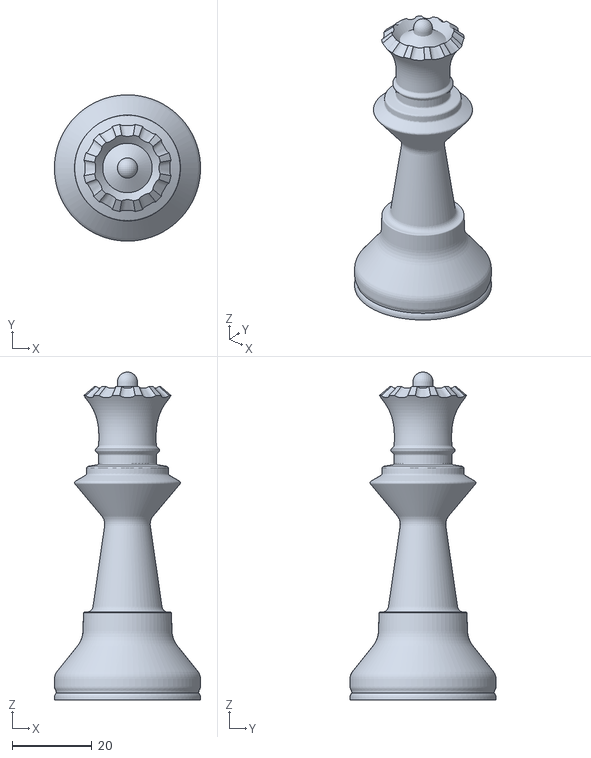
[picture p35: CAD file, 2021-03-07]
3D Simulatie/Queen.stl
36.8 x 36.8 x 82.5

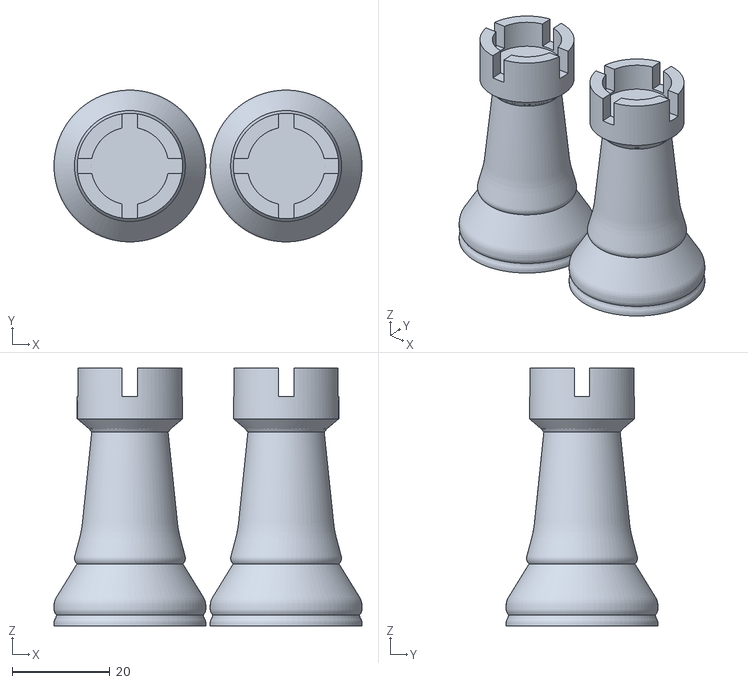
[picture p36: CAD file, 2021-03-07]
3D Simulatie/RookX2.stl
63.1 x 31.1 x 52.8

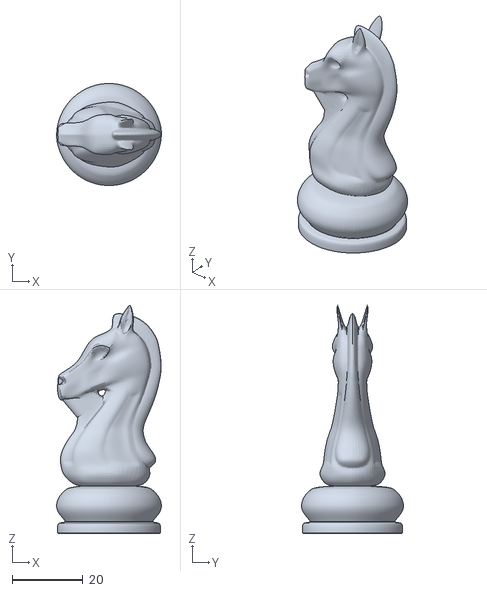
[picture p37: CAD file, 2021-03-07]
3D Simulatie/Knight.stl
29.7 x 28.9 x 64.6

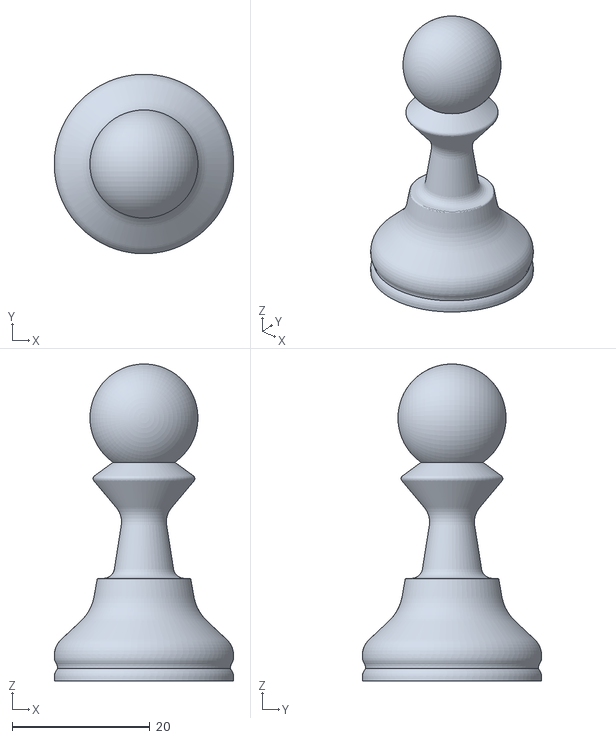
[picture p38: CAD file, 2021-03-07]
3D Simulatie/Pawn.stl
26.1 x 26.1 x 46.0

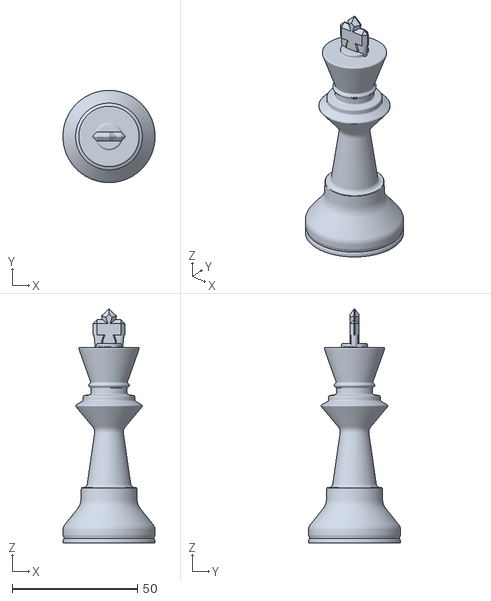
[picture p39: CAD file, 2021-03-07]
3D Simulatie/King-NEW.stl
36.8 x 36.7 x 93.2

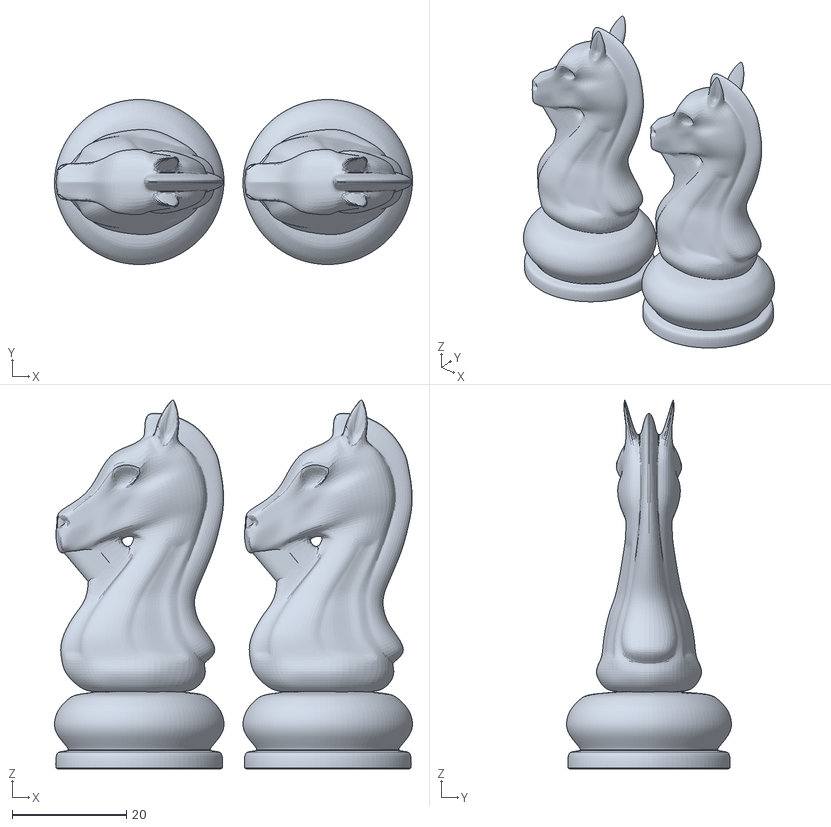
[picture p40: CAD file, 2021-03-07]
3D Simulatie/KnightX2.stl
62.7 x 28.9 x 64.6

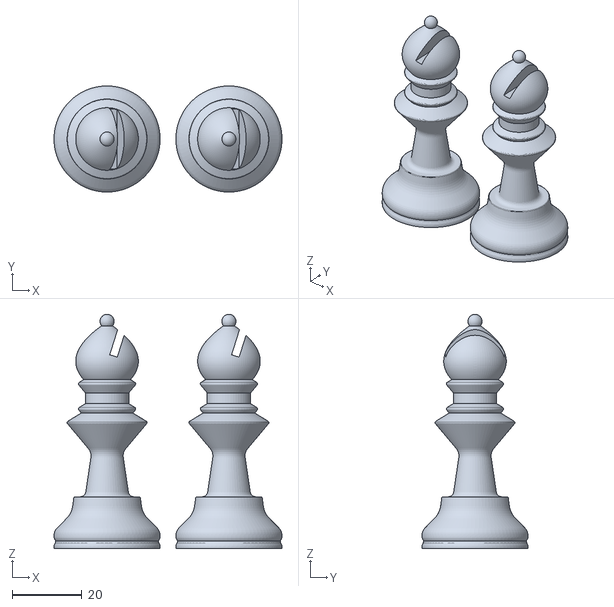
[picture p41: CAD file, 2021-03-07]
3D Simulatie/BishopX2.stl
65.5 x 30.5 x 67.3

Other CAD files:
3D Simulatie/Rook.stl
3D Simulatie/King.stl

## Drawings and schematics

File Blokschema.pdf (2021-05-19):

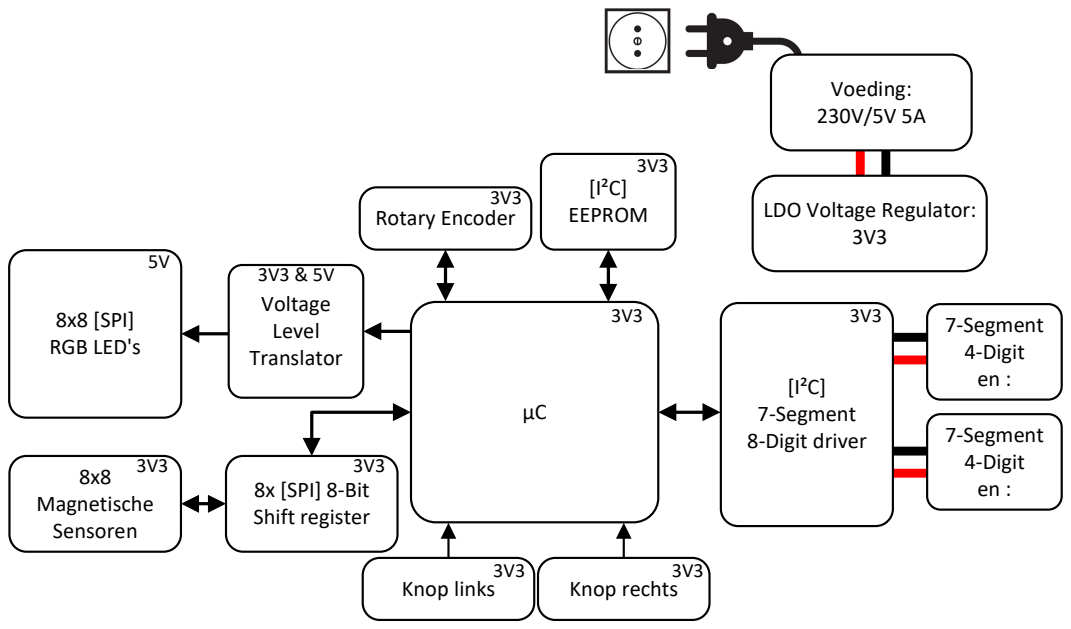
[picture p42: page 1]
Voeding: 230V/5V 5A; Rotary Encoder; 8x8 [SPI] RGB LED's; Voltage Level Translator; 8x8 Magnetische Sensoren; 8x [SPI] 8-Bit Shift register; [I²C] EEPROM; [I²C] 7-Segment 8-Digit driver; 7-Segment 4-Digit en :; Knop links; Knop rechts

LDO Voltage Regulator:

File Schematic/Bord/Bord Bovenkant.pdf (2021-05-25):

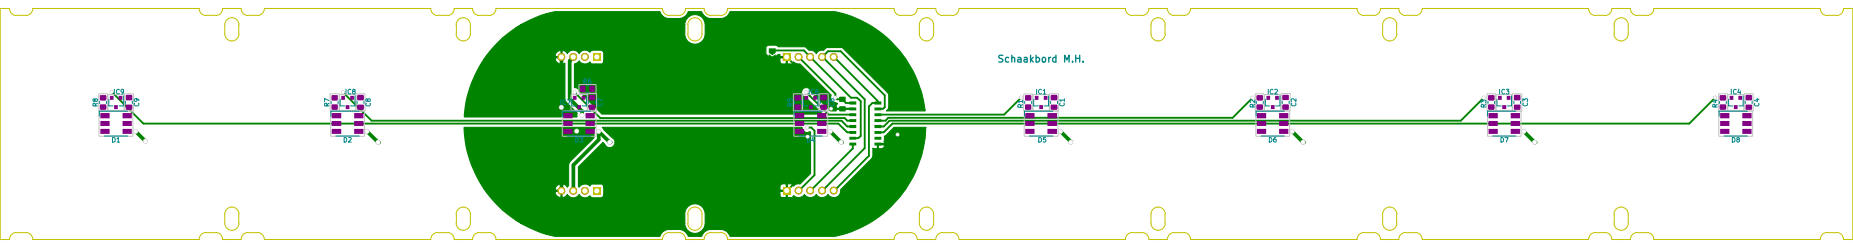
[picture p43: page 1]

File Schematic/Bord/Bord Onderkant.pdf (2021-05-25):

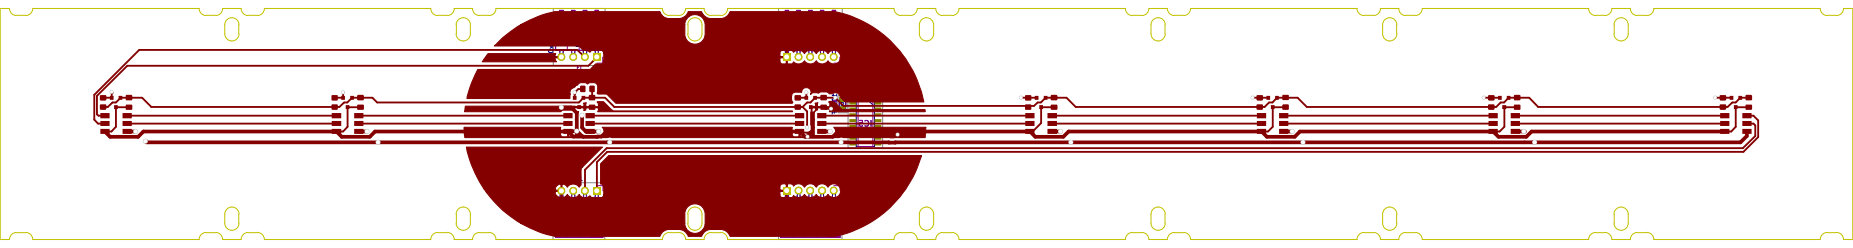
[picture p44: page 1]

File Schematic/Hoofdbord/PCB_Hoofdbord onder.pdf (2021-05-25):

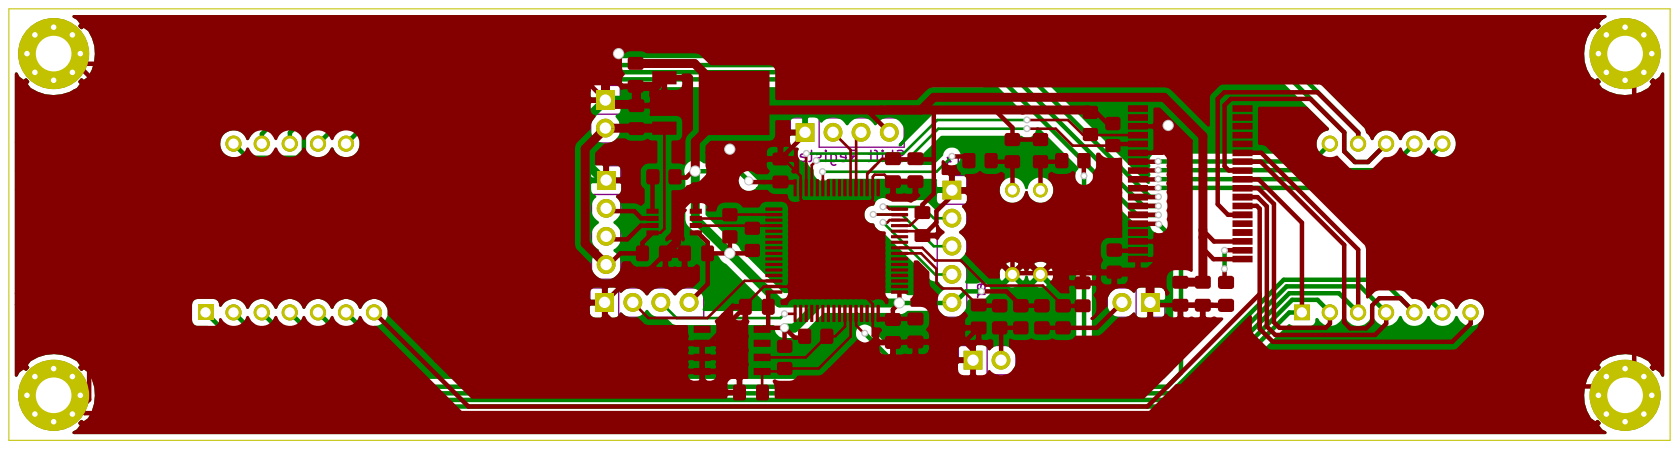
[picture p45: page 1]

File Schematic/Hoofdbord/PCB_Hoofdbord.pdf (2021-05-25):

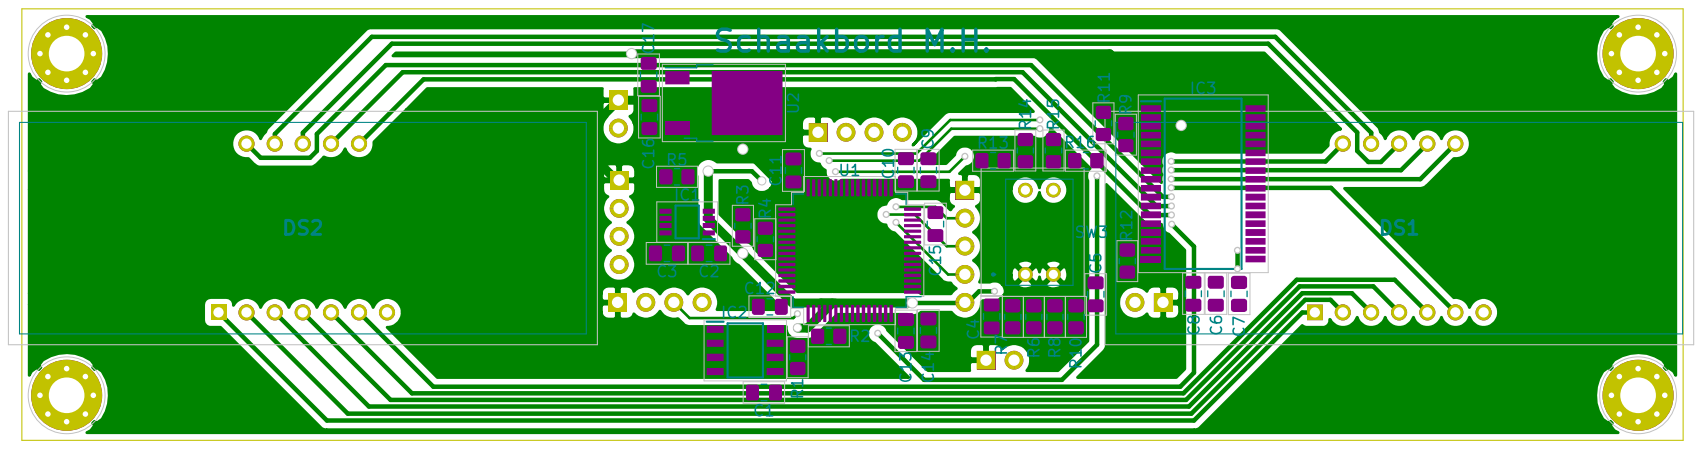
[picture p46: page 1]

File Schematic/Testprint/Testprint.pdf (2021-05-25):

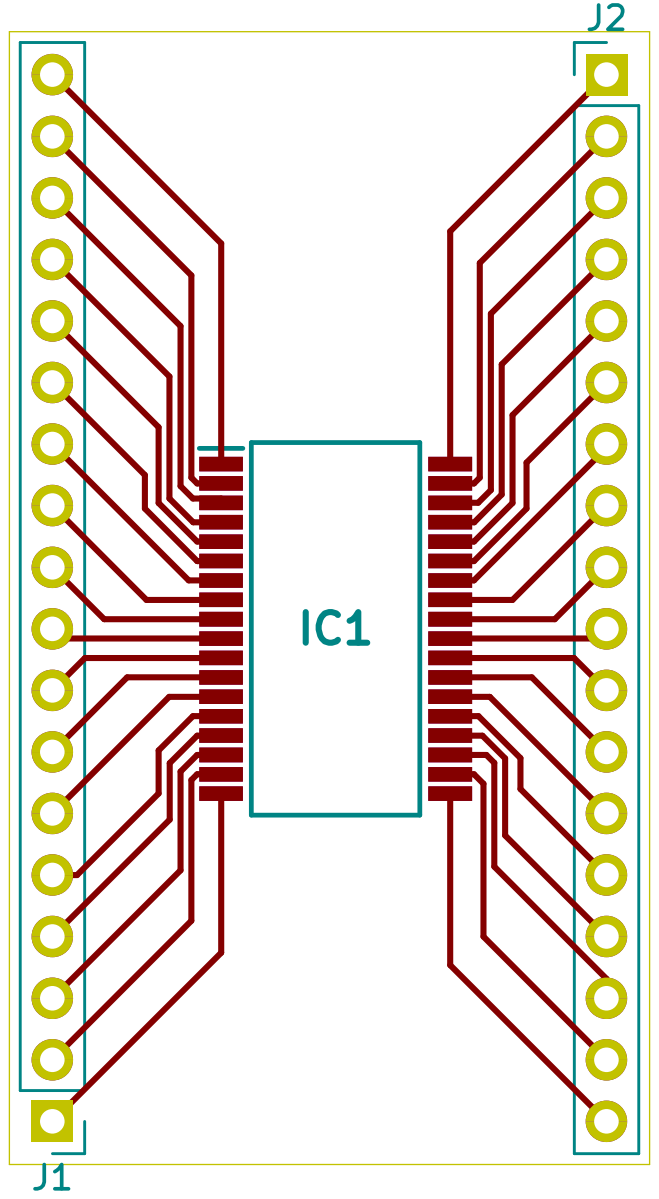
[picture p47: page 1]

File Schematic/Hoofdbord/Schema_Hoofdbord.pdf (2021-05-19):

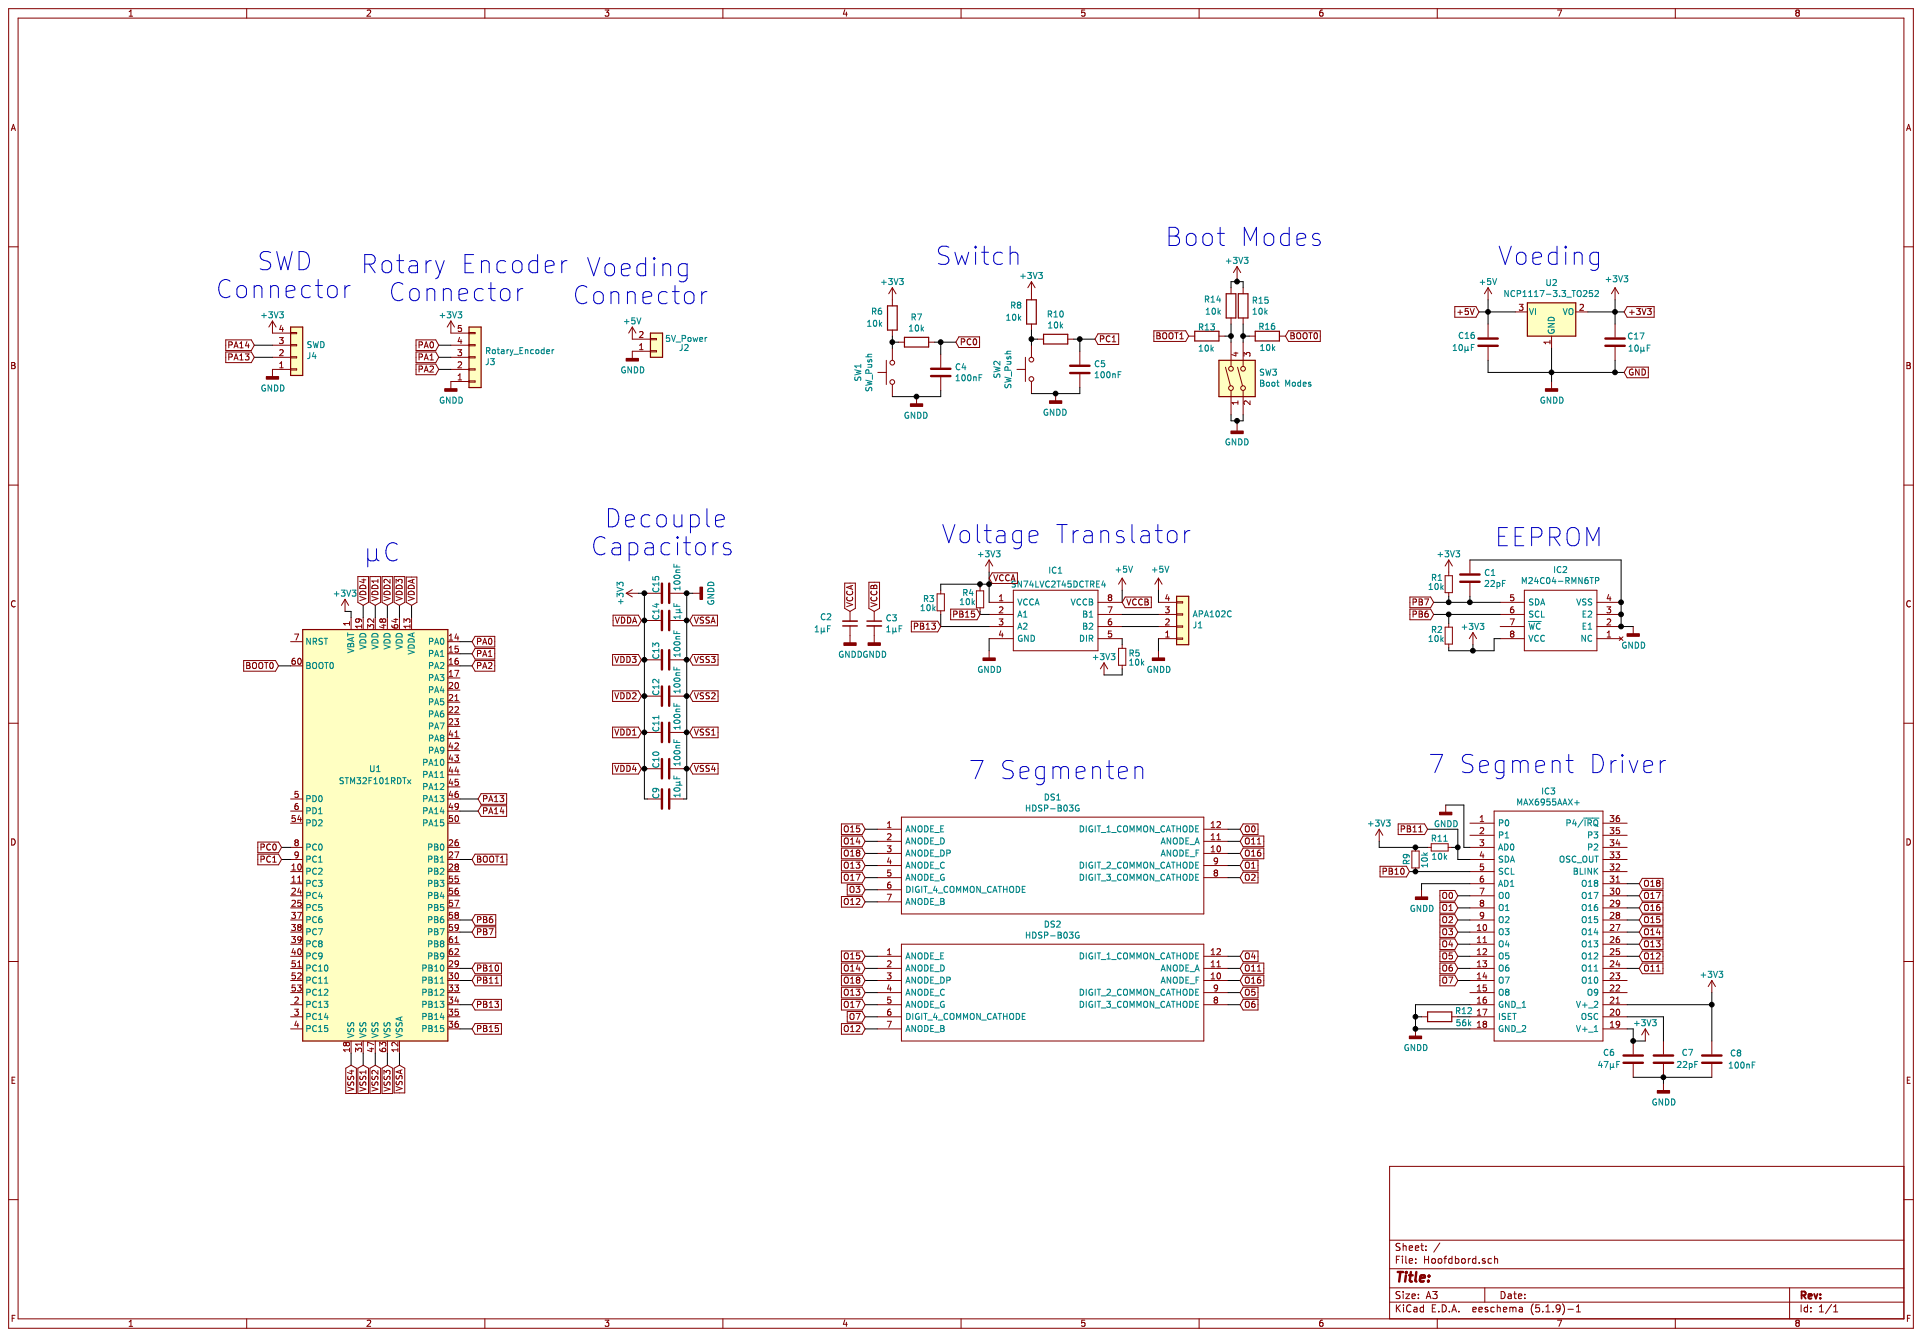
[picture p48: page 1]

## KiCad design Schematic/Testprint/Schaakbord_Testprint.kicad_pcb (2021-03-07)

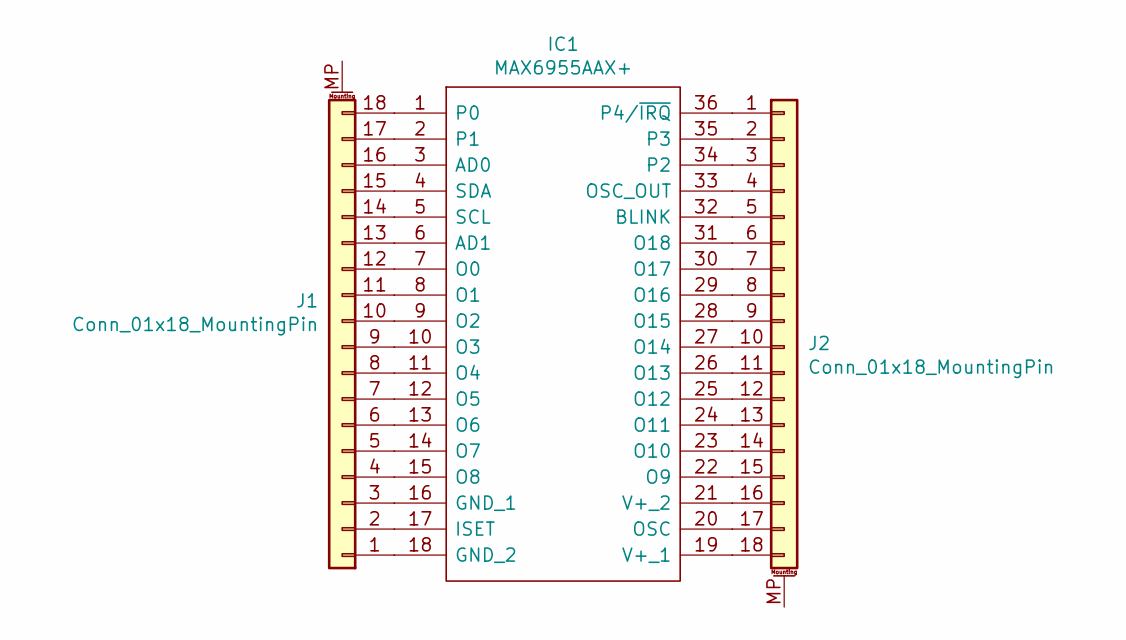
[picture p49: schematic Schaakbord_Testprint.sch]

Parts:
IC1: MAX6955AAX+; SOP80P1030X264-36N; Mouser Part Number 700-MAX6955AAX
J1, J2: Conn_01x18_MountingPin; PinHeader_1x18_P2.54mm_Vertical

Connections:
unnamed: IC1.1 (P0), J1.18
unnamed: IC1.2 (P1), J1.17
unnamed: IC1.3 (AD0), J1.16
unnamed: IC1.4 (SDA), J1.15
unnamed: IC1.5 (SCL), J1.14
unnamed: IC1.6 (AD1), J1.13
unnamed: IC1.7 (O0), J1.12
unnamed: IC1.8 (O1), J1.11
unnamed: IC1.9 (O2), J1.10
unnamed: IC1.10 (O3), J1.9
unnamed: IC1.11 (O4), J1.8
unnamed: IC1.12 (O5), J1.7
unnamed: IC1.13 (O6), J1.6
unnamed: IC1.14 (O7), J1.5
unnamed: IC1.15 (O8), J1.4
unnamed: IC1.16 (GND_1), J1.3
unnamed: IC1.17 (ISET), J1.2
unnamed: IC1.18 (GND_2), J1.1
unnamed: IC1.19 (V+_1), J2.18
unnamed: IC1.20 (OSC), J2.17
unnamed: IC1.21 (V+_2), J2.16
unnamed: IC1.22 (O9), J2.15
unnamed: IC1.23 (O10), J2.14
unnamed: IC1.24 (O11), J2.13
unnamed: IC1.25 (O12), J2.12
unnamed: IC1.26 (O13), J2.11
unnamed: IC1.27 (O14), J2.10
unnamed: IC1.28 (O15), J2.9
unnamed: IC1.29 (O16), J2.8
unnamed: IC1.30 (O17), J2.7
unnamed: IC1.31 (O18), J2.6
unnamed: IC1.32 (BLINK), J2.5
unnamed: IC1.33 (OSC_OUT), J2.4
unnamed: IC1.34 (P2), J2.3
unnamed: IC1.35 (P3), J2.2
unnamed: IC1.36 (P4/~IRQ), J2.1

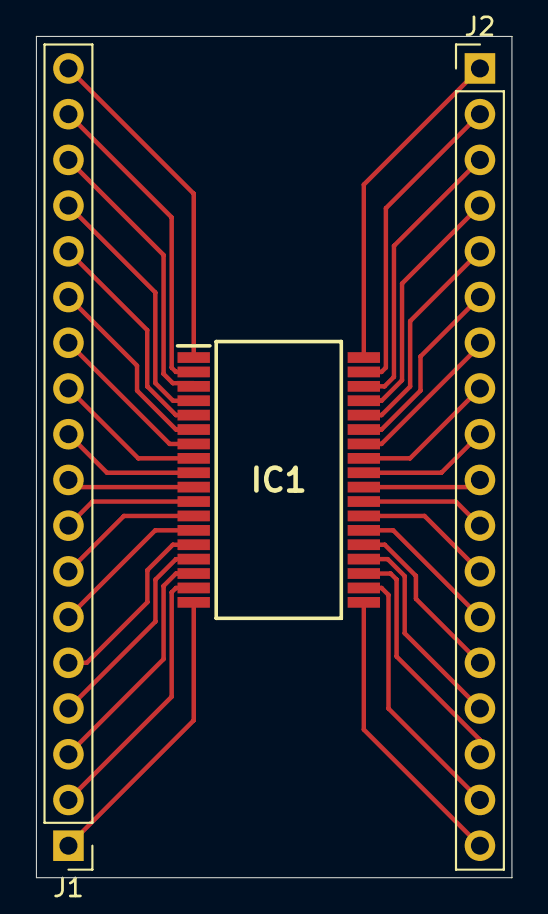
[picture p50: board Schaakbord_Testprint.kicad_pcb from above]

Board: 2 copper layers, 26.4 x 46.7 mm, 3 parts (0 on the bottom side), 36 nets.

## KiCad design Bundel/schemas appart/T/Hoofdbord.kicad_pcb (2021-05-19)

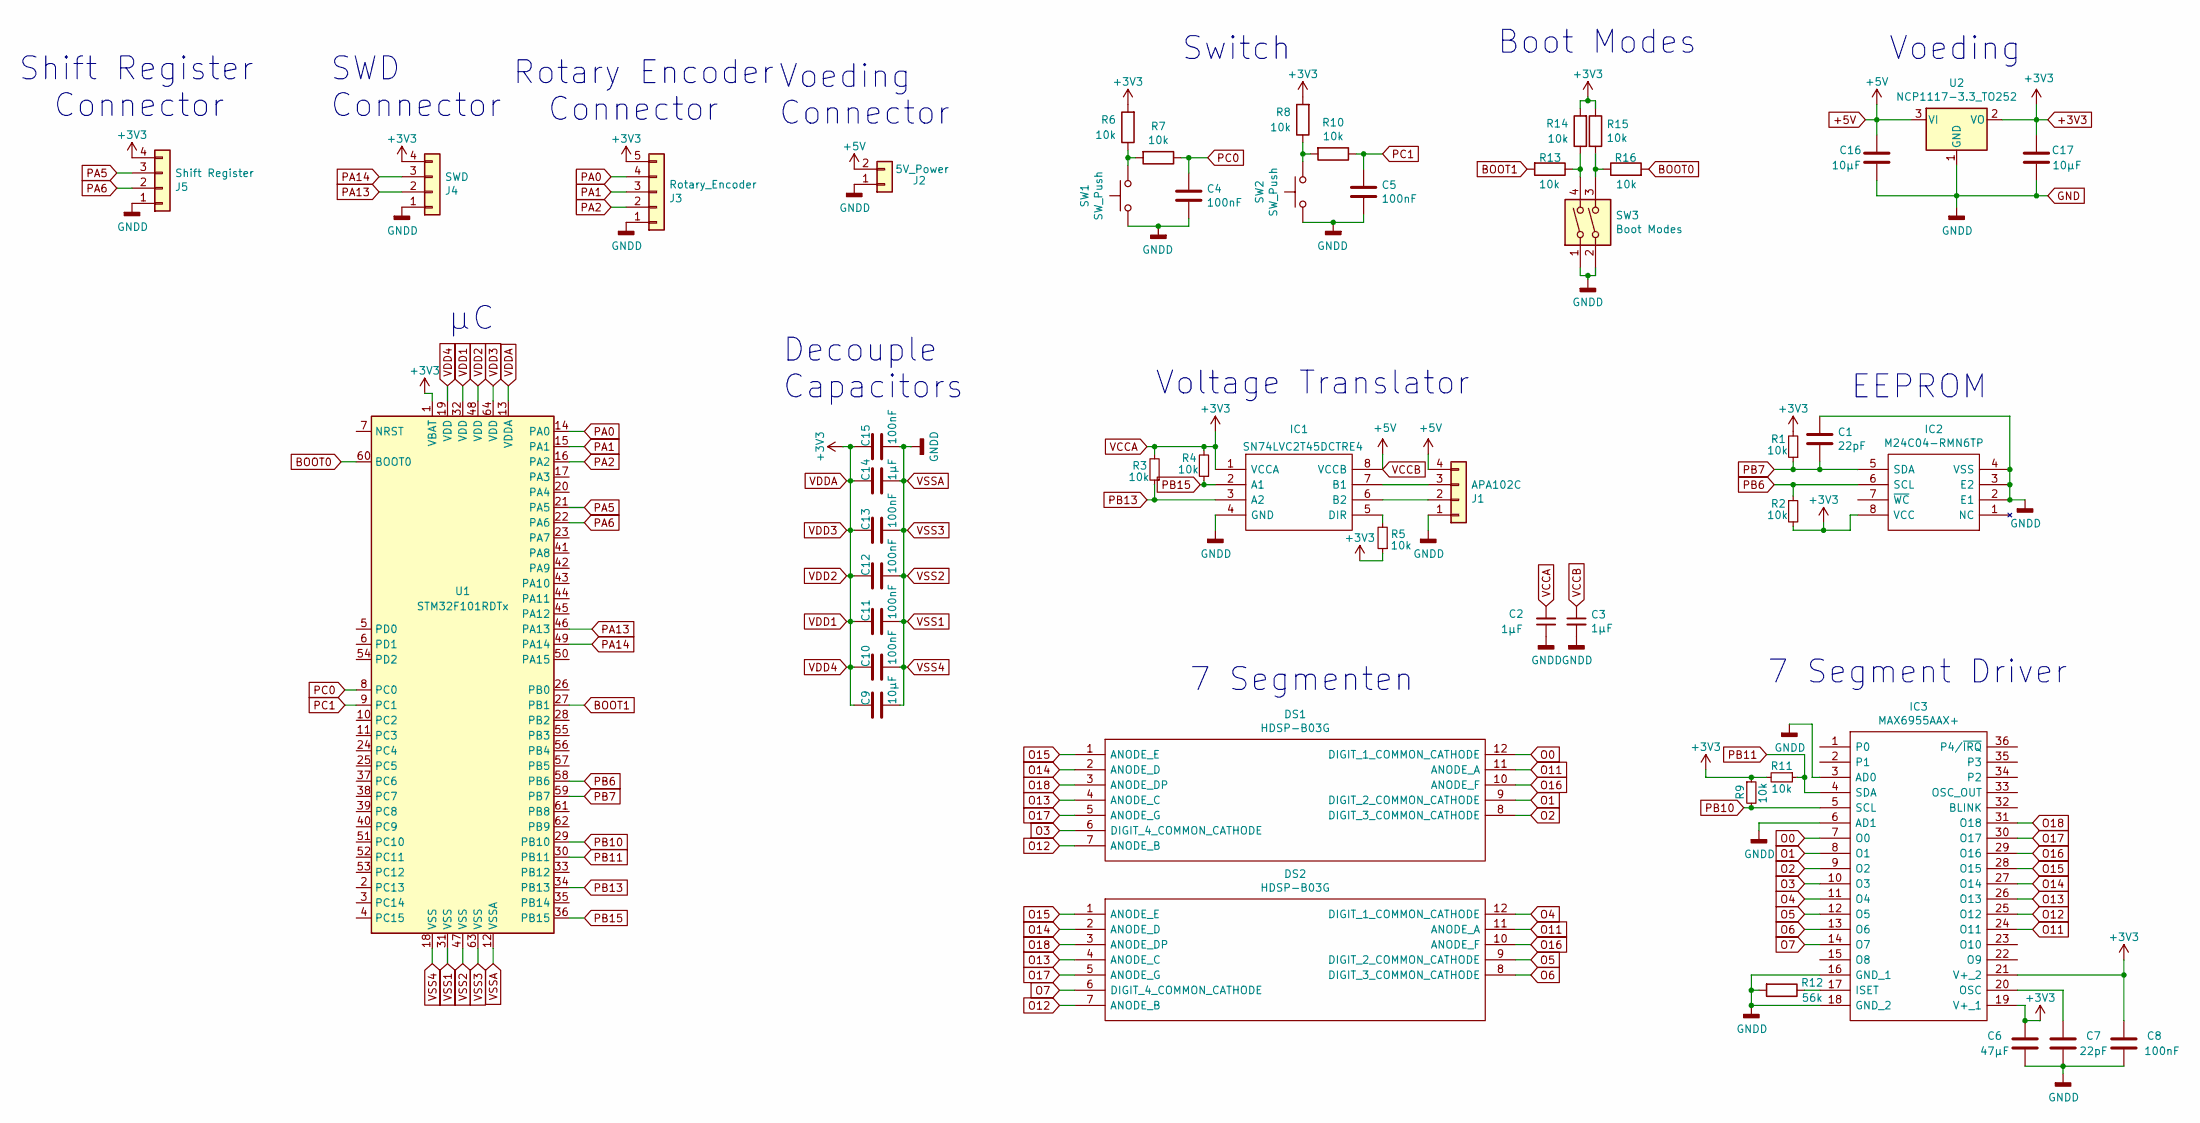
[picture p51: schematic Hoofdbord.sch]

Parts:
C1, C7: 22pF; C_0805_2012Metric_Pad1.18x1.45mm_HandSolder
C2, C3, C14: 1µF; C_0805_2012Metric_Pad1.18x1.45mm_HandSolder
C4, C5, C8, C10, C11, C12, C13, C15: 100nF; C_0805_2012Metric_Pad1.18x1.45mm_HandSolder
C6: 47µF; C_0805_2012Metric_Pad1.18x1.45mm_HandSolder
C9, C16, C17: 10µF; C_0805_2012Metric_Pad1.18x1.45mm_HandSolder
DS1, DS2: HDSP-B03G; HDSPB03G; Mouser Part Number 630-HDSP-B03G
IC1: SN74LVC2T45DCTRE4; SOP65P400X130-8N; Mouser Part Number 595-SN74LVC2T45DCTE4
IC2: M24C04-RMN6TP; SOIC127P600X175-8N; Mouser Part Number 511-M24C04-RMN6TP
IC3: MAX6955AAX+; SOP80P1030X264-36N; Mouser Part Number 700-MAX6955AAX
J1: APA102C; PinHeader_1x04_P2.54mm_Vertical
J2: 5V_Power; PinHeader_1x02_P2.54mm_Vertical
J3: Rotary_Encoder; PinHeader_1x05_P2.54mm_Vertical
J4: SWD; PinHeader_1x04_P2.54mm_Vertical
J5: Shift Register; PinHeader_1x04_P2.54mm_Vertical
R1, R2, R3, R4, R5, R6, R7, R8, R9, R10, R11, R13, R14, R15, R16: 10k; R_0805_2012Metric_Pad1.20x1.40mm_HandSolder
R12: 56k; R_0805_2012Metric_Pad1.20x1.40mm_HandSolder
SW1, SW2: SW_Push; PinHeader_1x02_P2.54mm_Vertical
SW3: Boot Modes; 418117270902
U1: STM32F101RDTx; LQFP-64_10x10mm_P0.5mm
U2: NCP1117-3.3_TO252; TO-252-2

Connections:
+3V3: C2.2, C6.2, C8.1, C9.2, C10.2, C11.2, C12.2, C13.2, C14.2, C15.2, C17.1, IC1.1 (VCCA), IC2.8 (VCC), IC3.19 (V+_1), IC3.21 (V+_2), J3.5, J4.4, J5.4, R1.2, R2.2, R3.2, R4.2, R5.1, R6.2, R8.2, R9.1, R11.2, R14.2, R15.1, U1.1 (VBAT), U1.13 (VDDA), U1.19 (VDD), U1.32 (VDD), U1.48 (VDD), U1.64 (VDD), U2.2 (VO)
+5V: C3.1, C16.2, IC1.8 (VCCB), J1.4, J2.2, U2.3 (VI)
BOOT0: R16.2, U1.60 (BOOT0)
BOOT1: R13.2, U1.27 (PB1)
GND: C1.1, C2.1, C3.2, C4.2, C5.2, C6.1, C7.1, C8.2, C9.1, C10.1, C11.1, C12.1, C13.1, C14.1, C15.1, C16.1, C17.2, IC1.4 (GND), IC2.2 (E1), IC2.3 (E2), IC2.4 (VSS), IC3.3 (AD0), IC3.6 (AD1), IC3.16 (GND_1), IC3.18 (GND_2), J1.1, J2.1, J3.1, J4.1, J5.1, R12.2, SW1.1, SW2.1, SW3.1, SW3.2, U1.12 (VSSA), U1.18 (VSS), U1.31 (VSS), U1.47 (VSS), U1.63 (VSS), U2.1 (GND)
unnamed: C7.2, IC3.20 (OSC)
unnamed: IC1.5 (DIR), R5.2
unnamed: IC1.6 (B2), J1.2
unnamed: IC1.7 (B1), J1.3
unnamed: IC3.17 (ISET), R12.1
unnamed: R6.1, R7.2, SW1.2
unnamed: R8.1, R10.2, SW2.2
unnamed: R13.1, R14.1, SW3.4
unnamed: R15.2, R16.1, SW3.3
O0: DS1.12 (DIGIT_1_COMMON_CATHODE), IC3.7 (O0)
O1: DS1.9 (DIGIT_2_COMMON_CATHODE), IC3.8 (O1)
O2: DS1.8 (DIGIT_3_COMMON_CATHODE), IC3.9 (O2)
O3: DS1.6 (DIGIT_4_COMMON_CATHODE), IC3.10 (O3)
O4: DS2.12 (DIGIT_1_COMMON_CATHODE), IC3.11 (O4)
O5: DS2.9 (DIGIT_2_COMMON_CATHODE), IC3.12 (O5)
O6: DS2.8 (DIGIT_3_COMMON_CATHODE), IC3.13 (O6)
O7: DS2.6 (DIGIT_4_COMMON_CATHODE), IC3.14 (O7)
O11: DS1.11 (ANODE_A), DS2.11 (ANODE_A), IC3.24 (O11)
O12: DS1.7 (ANODE_B), DS2.7 (ANODE_B), IC3.25 (O12)
O13: DS1.4 (ANODE_C), DS2.4 (ANODE_C), IC3.26 (O13)
O14: DS1.2 (ANODE_D), DS2.2 (ANODE_D), IC3.27 (O14)
O15: DS1.1 (ANODE_E), DS2.1 (ANODE_E), IC3.28 (O15)
O16: DS1.10 (ANODE_F), DS2.10 (ANODE_F), IC3.29 (O16)
O17: DS1.5 (ANODE_G), DS2.5 (ANODE_G), IC3.30 (O17)
O18: DS1.3 (ANODE_DP), DS2.3 (ANODE_DP), IC3.31 (O18)
PA0: J3.4, U1.14 (PA0)
PA1: J3.3, U1.15 (PA1)
PA2: J3.2, U1.16 (PA2)
PA5: J5.3, U1.21 (PA5)
PA6: J5.2, U1.22 (PA6)
PA13: J4.2, U1.46 (PA13)
PA14: J4.3, U1.49 (PA14)
PB6: IC2.6 (SCL), R2.1, U1.58 (PB6)
PB7: C1.2, IC2.5 (SDA), R1.1, U1.59 (PB7)
PB10: IC3.5 (SCL), R9.2, U1.29 (PB10)
PB11: IC3.4 (SDA), R11.1, U1.30 (PB11)
PB13: IC1.3 (A2), R3.1, U1.34 (PB13)
PB15: IC1.2 (A1), R4.1, U1.36 (PB15)
PC0: C4.1, R7.1, U1.8 (PC0)
PC1: C5.1, R10.1, U1.9 (PC1)

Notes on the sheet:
EEPROM
Switch
Boot Modes
SWD Connector
Voeding
7 Segmenten
7 Segment Driver
Voltage Translator
Voeding Connector
Decouple Capacitors
Shift Register Connector
Rotary Encoder Connector

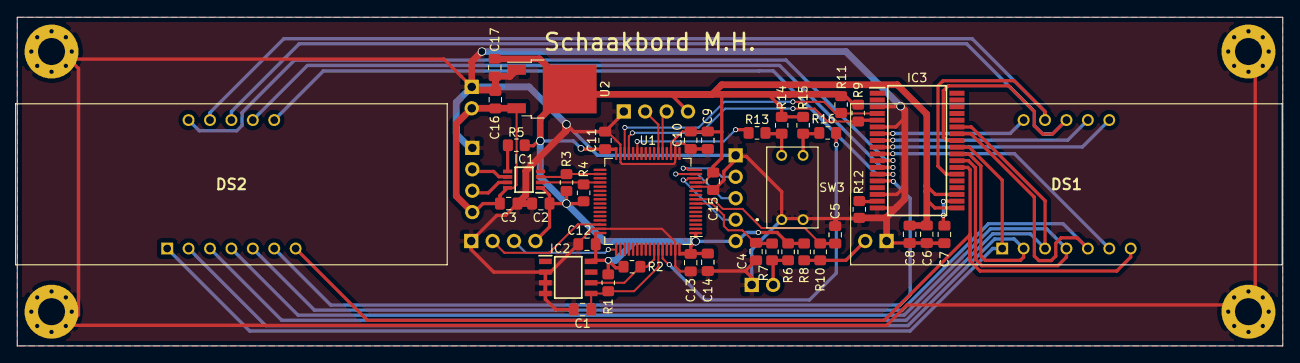
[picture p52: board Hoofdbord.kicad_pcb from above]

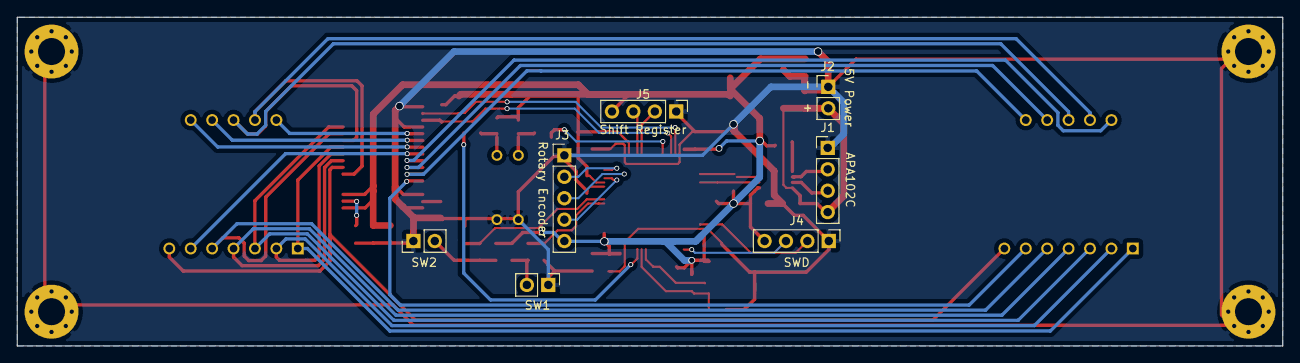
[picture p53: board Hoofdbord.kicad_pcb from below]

Board: 2 copper layers, 150.1 x 39.0 mm, 48 parts (7 on the bottom side), 45 nets.

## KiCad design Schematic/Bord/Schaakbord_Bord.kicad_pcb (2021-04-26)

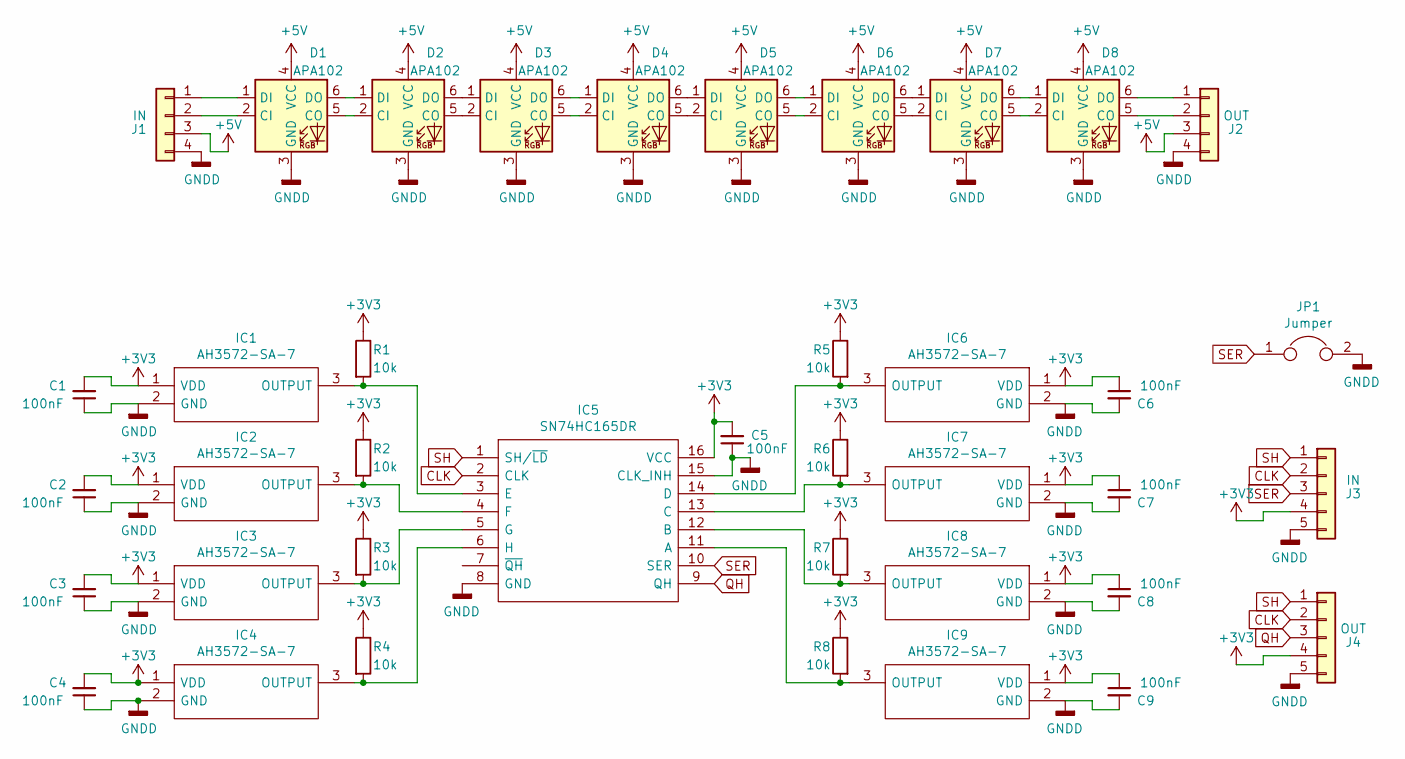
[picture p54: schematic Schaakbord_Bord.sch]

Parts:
C1, C2, C3, C4, C5, C6, C7, C8, C9: 100nF; C_0805_2012Metric_Pad1.18x1.45mm_HandSolder
D1, D2, D3, D4, D5, D6, D7, D8: APA102; LED_RGB_5050-6
IC1, IC2, IC3, IC4, IC6, IC7, IC8, IC9: AH3572-SA-7; SOT-23_Handsoldering; Mouser Part Number 621-AH3572-SA-7
IC5: SN74HC165DR; SOIC127P600X175-16N; Mouser Part Number 595-SN74HC165DR
J1: IN; PinHeader_1x04_P2.54mm_Horizontal
J2: OUT; PinSocket_1x04_P2.54mm_Horizontal
J3: IN; PinHeader_1x05_P2.54mm_Horizontal
J4: OUT; PinSocket_1x05_P2.54mm_Horizontal
JP1: Jumper; SolderJumper-2_P1.3mm_Open_TrianglePad1.0x1.5mm
R1, R2, R3, R4, R5, R6, R7, R8: 10k; R_0805_2012Metric_Pad1.20x1.40mm_HandSolder

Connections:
+3V3: C1.2, C2.2, C3.2, C4.2, C5.2, C6.1, C7.1, C8.1, C9.1, IC1.1 (VDD), IC2.1 (VDD), IC3.1 (VDD), IC4.1 (VDD), IC5.16 (VCC), IC6.1 (VDD), IC7.1 (VDD), IC8.1 (VDD), IC9.1 (VDD), J3.4, J4.4, R1.1, R2.1, R3.1, R4.1, R5.1, R6.1, R7.1, R8.1
+5V: D1.4 (VCC), D2.4 (VCC), D3.4 (VCC), D4.4 (VCC), D5.4 (VCC), D6.4 (VCC), D7.4 (VCC), D8.4 (VCC), J1.3, J2.3
CLK: IC5.2 (CLK), J3.2, J4.2
GNDD: C1.1, C2.1, C3.1, C4.1, C5.1, C6.2, C7.2, C8.2, C9.2, D1.3 (GND), D2.3 (GND), D3.3 (GND), D4.3 (GND), D5.3 (GND), D6.3 (GND), D7.3 (GND), D8.3 (GND), IC1.2 (GND), IC2.2 (GND), IC3.2 (GND), IC4.2 (GND), IC5.8 (GND), IC5.15 (CLK_INH), IC6.2 (GND), IC7.2 (GND), IC8.2 (GND), IC9.2 (GND), J1.4, J2.4, J3.5, J4.5, JP1.2
unnamed: D1.1 (DI), J1.1
unnamed: D1.2 (CI), J1.2
unnamed: D1.5 (CO), D2.2 (CI)
unnamed: D1.6 (DO), D2.1 (DI)
unnamed: D2.5 (CO), D3.2 (CI)
unnamed: D2.6 (DO), D3.1 (DI)
unnamed: D3.5 (CO), D4.2 (CI)
unnamed: D3.6 (DO), D4.1 (DI)
unnamed: D4.5 (CO), D5.2 (CI)
unnamed: D4.6 (DO), D5.1 (DI)
unnamed: D5.5 (CO), D6.2 (CI)
unnamed: D5.6 (DO), D6.1 (DI)
unnamed: D6.5 (CO), D7.2 (CI)
unnamed: D6.6 (DO), D7.1 (DI)
unnamed: D7.5 (CO), D8.2 (CI)
unnamed: D7.6 (DO), D8.1 (DI)
unnamed: D8.5 (CO), J2.2
unnamed: D8.6 (DO), J2.1
unnamed: IC1.3 (OUTPUT), IC5.3 (E), R1.2
unnamed: IC2.3 (OUTPUT), IC5.4 (F), R2.2
unnamed: IC3.3 (OUTPUT), IC5.5 (G), R3.2
unnamed: IC4.3 (OUTPUT), IC5.6 (H), R4.2
unnamed: IC5.11 (A), IC9.3 (OUTPUT), R8.2
unnamed: IC5.12 (B), IC8.3 (OUTPUT), R7.2
unnamed: IC5.13 (C), IC7.3 (OUTPUT), R6.2
unnamed: IC5.14 (D), IC6.3 (OUTPUT), R5.2
QH: IC5.9 (QH), J4.3
SER: IC5.10 (SER), J3.3, JP1.1
SH: IC5.1 (SH/~LD), J3.1, J4.1

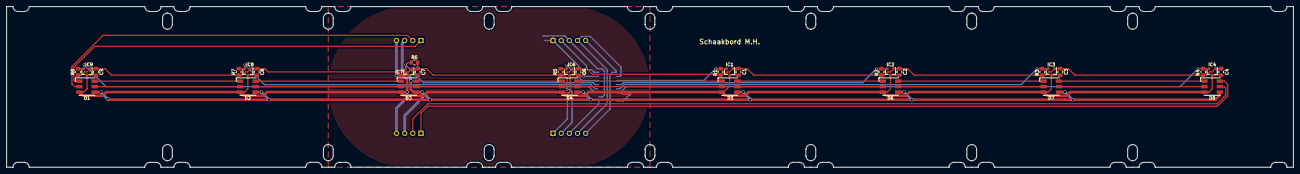
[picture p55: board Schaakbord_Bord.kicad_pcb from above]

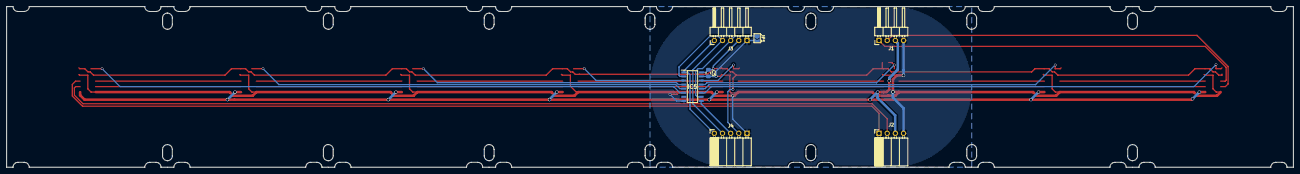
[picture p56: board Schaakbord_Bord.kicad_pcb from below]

Board: 2 copper layers, 400.3 x 50.0 mm, 39 parts (7 on the bottom side), 33 nets.

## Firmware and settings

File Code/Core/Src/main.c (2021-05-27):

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
/* Includes ------------------------------------------------------------------*/
#include "main.h"

/* USER CODE BEGIN Includes */
 // RGB LED's
#include "APA102C.h"
 // 7-Segment Driver
#include "MAX6955.h"
 // EEPROM
#include "M24C04.h"
 // Shift Register Parallel In Serieëel Out
#include "PISO.h"

/* USER CODE END Includes */

I2C_HandleTypeDef hi2c1;
I2C_HandleTypeDef hi2c2;

TIM_HandleTypeDef htim2;
TIM_HandleTypeDef htim3;
TIM_HandleTypeDef htim4;

/* USER CODE BEGIN PV */
uint8_t buf[15];
uint8_t secondenR = 5;
uint8_t TsecondenR = 0;
uint8_t minutenR = 0;
uint8_t TminutenR = 0;

uint8_t secondenL = 5;
uint8_t TsecondenL = 0;
uint8_t minutenL = 0;
uint8_t TminutenL = 0;

/* USER CODE END PV */

void SystemClock_Config(void);
static void MX_GPIO_Init(void);
static void MX_I2C2_Init(void);
static void MX_I2C1_Init(void);
static void MX_TIM3_Init(void);
static void MX_TIM2_Init(void);
static void MX_TIM4_Init(void);
/* USER CODE BEGIN 0 */
void SysTickDelayCount2(unsigned long ulCount){
    CoreDebug->DEMCR |= CoreDebug_DEMCR_TRCENA_Msk;
    ITM->LAR = 0xC5ACCE55; // Unlock de counter
    DWT->CYCCNT = 0; // Reset de cycle counter
    DWT->CTRL |= DWT_CTRL_CYCCNTENA_Msk; // Enable/start de counter

    while(DWT->CYCCNT < ulCount);
}
/* USER CODE END 0 */

/**
  * @brief  The application entry point.
  * @retval int
  */
int main(void)
{
  /* MCU Configuration--------------------------------------------------------*/

  /* Reset of all peripherals, Initializes the Flash interface and the Systick. */
  HAL_Init();

  /* Configure the system clock */
  SystemClock_Config();

  /* Initialize all configured peripherals */
  MX_GPIO_Init();
  MX_I2C2_Init();
  MX_I2C1_Init();
  MX_TIM3_Init();
  MX_TIM2_Init();
  MX_TIM4_Init();
  /* USER CODE BEGIN 2 */
  // 7-segment aansturen in test stand
	  SS_Start(0);

	  SS_Schrijf(0, TminutenR, 1);
	  SS_Schrijf(1, minutenR, 1);
	  SS_Schrijf(2, TsecondenR, 1);
	  SS_Schrijf(3, secondenR, 1);

	  SS_Schrijf(4, TminutenL, 1);
	  SS_Schrijf(5, minutenL, 1);
	  SS_Schrijf(6, TsecondenL, 1);
	  SS_Schrijf(7, secondenL, 1);


  // APA102C's aansturen

	  LED_Start();
	  for (uint8_t i = 0; i < 9; i++){
		  (i % 2 == 0) ? LED_Groen(50) : LED_RGB(50, 50, 50);
	  }
	  HAL_Delay(5000);

	  HAL_TIM_Encoder_Start(&htim2, TIM_CHANNEL_ALL);
  /* USER CODE END 2 */

  /* Infinite loop */
  /* USER CODE BEGIN WHILE */
  while (1)
  {
    /* USER CODE END WHILE */

    /* USER CODE BEGIN 3 */
	  minutenR = ((TIM2->CNT)<1);

	  Meten();
	  minutenR = ((TIM2->CNT)<1);
	  HAL_Delay(1);

	  Controle();
	  minutenR = ((TIM2->CNT)<1);
	  HAL_Delay(1);

  }
  /* USER CODE END 3 */
}

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
/* USER CODE BEGIN 4 */
void HAL_TIM_PeriodElapsedCallback(TIM_HandleTypeDef *htim){
	if (htim == &htim4){
		if (secondenR != 0){
			secondenR--;
		} else if (TsecondenR != 0){
			secondenR = 9;
			TsecondenR--;
		} else if (minutenR != 0){
			secondenR = 9;
			TsecondenR = 5;
			minutenR--;
		} else if (TminutenR != 0){
			secondenR = 9;
			TsecondenR = 5;
			minutenR = 9;
			TminutenR--;
		}
	}

	if (htim == &htim3){
		if (secondenL != 0){
			secondenL--;
		} else if (TsecondenL != 0){
			secondenL = 9;
			TsecondenL--;
		} else if (minutenL != 0){
			secondenL = 9;
			TsecondenL = 5;
			minutenL--;
		} else if (TminutenL != 0){
			secondenL = 9;
			TsecondenL = 5;
			minutenL = 9;
			TminutenL--;
		}
	}

	if (secondenR == 0 && TsecondenR == 0 && minutenR == 0 && TminutenR == 0 && (secondenL == 0 && TsecondenL == 0 && minutenL == 0 && TminutenL == 0) == 0 ){
		SS_Schrijf(0, 0xAD, 0);
		SS_Schrijf(1, 0xAD, 0);
		SS_Schrijf(2, 0xAD, 0);
		SS_Schrijf(3, 0xAD, 0);

		SS_Schrijf(4, TminutenL, 1);
		SS_Schrijf(5, minutenL, 1);
		SS_Schrijf(6, TsecondenL, 1);
		SS_Schrijf(7, secondenL, 1);

	} else if (secondenL == 0 && TsecondenL == 0 && minutenL == 0 && TminutenL == 0 && (secondenR == 0 && TsecondenR == 0 && minutenR == 0 && TminutenR == 0) == 0 ){
		SS_Schrijf(0, TminutenR, 1);
		SS_Schrijf(1, minutenR, 1);
		SS_Schrijf(2, TsecondenR, 1);
		SS_Schrijf(3, secondenR, 1);

		SS_Schrijf(4, 0xAD, 0);
		SS_Schrijf(5, 0xAD, 0);
		SS_Schrijf(6, 0xAD, 0);
		SS_Schrijf(7, 0xAD, 0);

	} else if (secondenL == 0 && TsecondenL == 0 && minutenL == 0 && TminutenL == 0 && secondenR == 0 && TsecondenR == 0 && minutenR == 0 && TminutenR == 0){
		SS_Schrijf(0, 0xAD, 0);
		SS_Schrijf(1, 0xAD, 0);
		SS_Schrijf(2, 0xAD, 0);
		SS_Schrijf(3, 0xAD, 0);

		SS_Schrijf(4, 0xAD, 0);
		SS_Schrijf(5, 0xAD, 0);
		SS_Schrijf(6, 0xAD, 0);
		SS_Schrijf(7, 0xAD, 0);

	} else {
		SS_Schrijf(0, TminutenR, 1);
		SS_Schrijf(1, minutenR, 1);
		SS_Schrijf(2, TsecondenR, 1);
		SS_Schrijf(3, secondenR, 1);

		SS_Schrijf(4, TminutenL, 1);
		SS_Schrijf(5, minutenL, 1);
		SS_Schrijf(6, TsecondenL, 1);
		SS_Schrijf(7, secondenL, 1);
	}
}

void HAL_GPIO_EXTI_Callback(uint16_t GPIO_Pin){
	if (GPIO_Pin == SWR_Pin){
		HAL_TIM_Base_Stop_IT(&htim4);
		HAL_TIM_Base_Start_IT(&htim3);
	}

	if (GPIO_Pin == SWL_Pin){
		HAL_TIM_Base_Stop_IT(&htim3);
		HAL_TIM_Base_Start_IT(&htim4);
	}
}
/* USER CODE END 4 */
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


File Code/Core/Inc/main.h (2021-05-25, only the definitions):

#define SWR_Pin GPIO_PIN_0
#define SWR_GPIO_Port GPIOC
#define SWR_EXTI_IRQn EXTI0_IRQn
#define SWL_Pin GPIO_PIN_1
#define SWL_GPIO_Port GPIOC
#define SWL_EXTI_IRQn EXTI1_IRQn
#define SPI1_CS_Pin GPIO_PIN_2
#define SPI1_CS_GPIO_Port GPIOA
#define SPI1_CLK_Pin GPIO_PIN_5
#define SPI1_CLK_GPIO_Port GPIOA
#define SPI1_MISO_Pin GPIO_PIN_6
#define SPI1_MISO_GPIO_Port GPIOA
#define SPI2_SCK_Pin GPIO_PIN_13
#define SPI2_SCK_GPIO_Port GPIOB
#define SPI2_MOSI_Pin GPIO_PIN_15
#define SPI2_MOSI_GPIO_Port GPIOB

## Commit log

2021-03-07 files -> Pionnen
    [Bishop.stl, BishopX2.stl, King-NEW.stl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]
2021-03-07 Update voorbeeld sensor.jpg
2021-03-23 Update Schema
    [Schaakbord.sch]
2021-04-12 Update schematic
    [Schaakbord.sch]
2021-04-15 Schematic Update
    [Schaakbord.sch]
2021-04-22 Update PCB
    [Hoofdbord.kicad_pcb, Schaakbord_Bord.kicad_pcb, Schaakbord_Bord.sch]
2021-04-26 Ontwerp Update
    [Hoofdbord-B_Cu.gbr, Hoofdbord-B_Mask.gbr, Hoofdbord-B_SilkS.gbr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]
2021-05-19 Lot's of changes
    [Berekening verbruik.xlsx, Berekening vermogen dissiperen.xlsx, Bishop.stl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]

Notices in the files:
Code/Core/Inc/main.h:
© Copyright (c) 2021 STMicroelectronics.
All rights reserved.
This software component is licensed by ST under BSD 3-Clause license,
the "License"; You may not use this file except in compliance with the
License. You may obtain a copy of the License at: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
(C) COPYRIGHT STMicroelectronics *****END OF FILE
